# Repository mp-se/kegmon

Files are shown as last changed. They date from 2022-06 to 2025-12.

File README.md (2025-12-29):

 









# KegMon - Monitoring the volume in your kegs

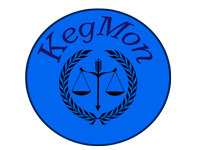
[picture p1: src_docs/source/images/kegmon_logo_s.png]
KegMon Logo


This is a project that I have done for my own Keezer, if you like it please feel free to suggest improvements. 

For docs see: https://mp-se.github.io/kegmon/index.html

# Hardware

* Supports ESP8266 D1 mini, ESP32s2 mini or ESP32s3 mini
* Loadcells and HX711/NAU7802 ADC converters
* DS18B20, DHT22, BME280 or BrewPI(IP) temperature sensors
* OLED 0.96" or LCD 20x4/20x2 displays

# Features

* Can measure weight from 1 or 2 scales
* Stable scale presentation (data is filtered and processed)
* Support temperature/humidity sensor in one scale base
* Integration with Brewfather to retrive data on brew
* Integration with Brewspy to retrive data on brew and also update the remaning volume and pours
* Integration with Home Assistant
* Weights and Volumes in Metric, Imperial (both US and UK)
* Pour detection for pours over 100 ml
* Estimation on how many glasses remain in the kegs
* Firmware update via UI
* One build for all hardware options
* Modern HTML5 UI
* Easy scale calibration
* 3D models and PCB

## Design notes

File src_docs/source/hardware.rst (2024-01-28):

.. _hardware:

Hardware 
--------

Introduction
============

The software will adopt to what external sensors are connected and will work with 
one, two scales, one or two displays and with/without a temperature sensor. 

The graph here shows two of my scales in my keezer where the second one (lower graph) is quite 
stable over time. The first one is not. The difference is over 2 kg and it goes back to the previous 
weight after a few hours. 

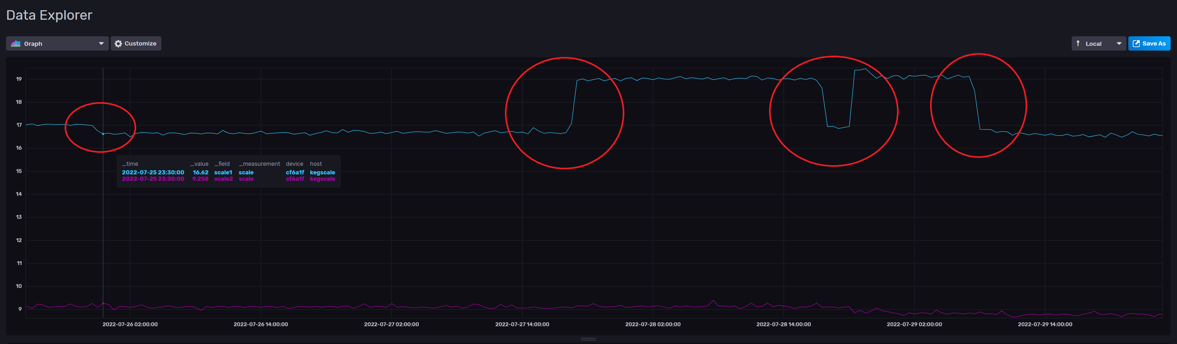
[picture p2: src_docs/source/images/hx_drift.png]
Scale drift


HX711
=====

I found 3 main types of HX711 boards and the green board has a different pin configuration compared to the 
other boards. 

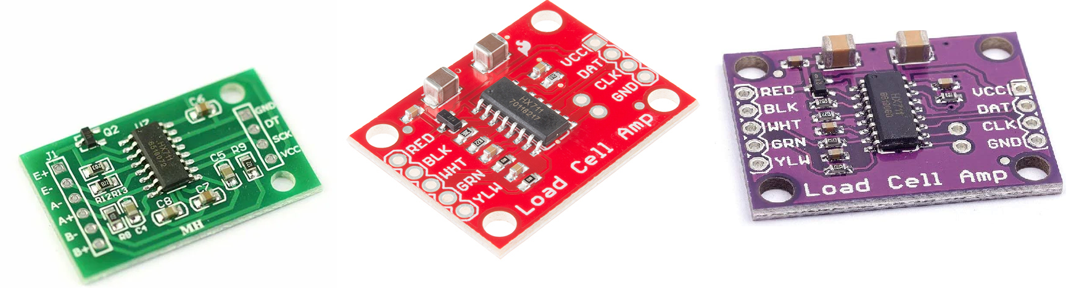
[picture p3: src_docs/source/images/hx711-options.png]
HX711 boards


* Green: Most common board when searching for HX711
* Red: Sparkfun board
* Purple: A variation of the Sparkfun board

The SparkFun board is the most expensive one but has one major advantage. You can power it on +5V and 
configure it to use 3.3V digital signal levels (using VCC and VDD pins). 

The main option used in this project is the purple HX711 board. The green board dont have the same pin configiuration 
so this will not work with the PCB design.

NAU7802
=======

This is the alternative ADC which is quite new and I have not had the time yet to validate the long term stability. 

These boards use the I2C bus for communication so these needs a differnt hardware wiring. Since you cannot change the 
adress on these boards you need to an ESP32 if two scales will be connected since the ESP8266 only supports one I2C bus.

.. note::
  If you are using this you need to change this in the configuration menu and restart the device for it to work 
  properly. 

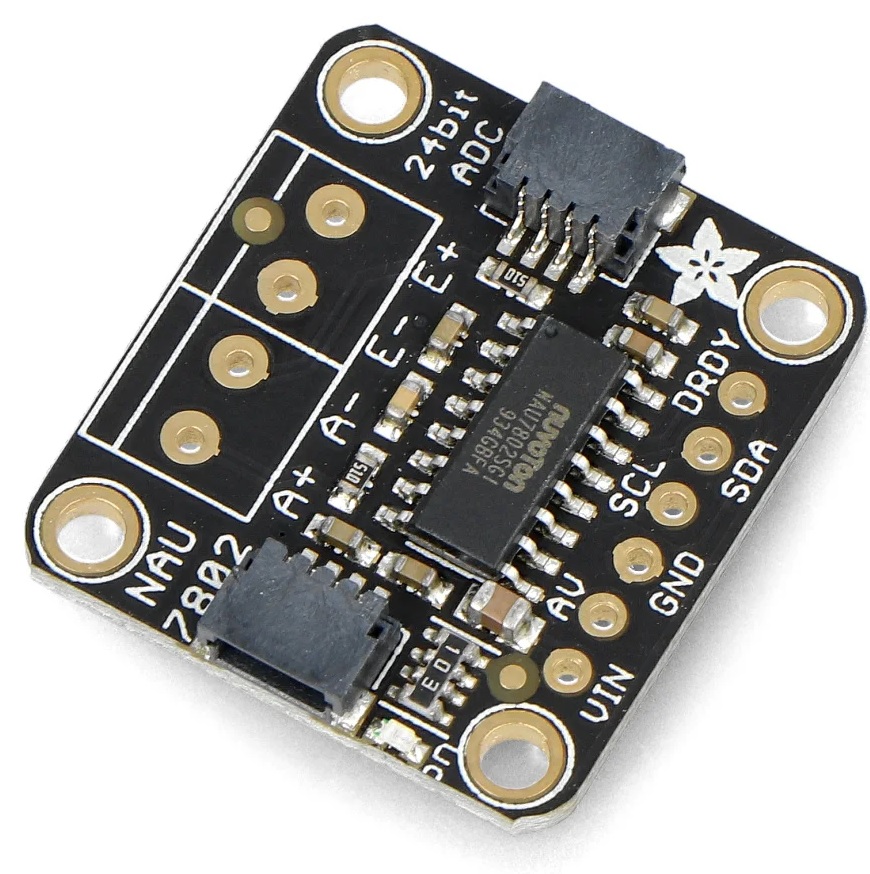
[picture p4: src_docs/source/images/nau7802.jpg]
NAU7802


Schema for HX711
================

.. note::
  The temperature sensor is installed in the scale base and you can use either a DS18B20, DHT22 or BME280. I would recommend 
  the DS18B20 since that is more stable and cheaper than the DHT22. The BME280 uses an I2C bus so this will require a different 
  wiring than the other options.

This is the schema used for the default hardware options. 

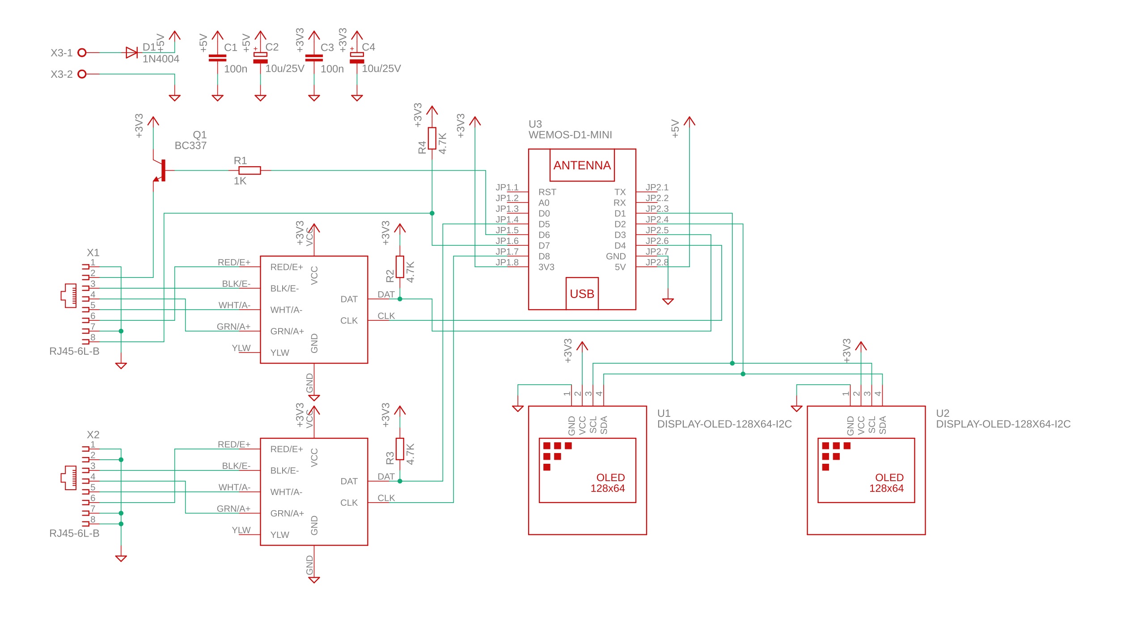
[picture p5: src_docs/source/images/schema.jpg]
Default hardware options


Schema for NAU7802
==================

This is the schema used for the NAU7802 boards. Scale 1 uses the same pins as the OLED displays. Scale 2 uses the same pins as 
for the HX711. So D3/D4 is unused in this variant. 

.. note::
  I'm considering to update the hardware design to fit a larger OLED display 1.3" and multiple NAU7802 on the ESP8266 platform but 
  this will require an i2c extender to avoid adress overlap. 

.. note::
  Note that the ESP8266 only supports one I2C bus so with that processor only one scale can be used. Recommend to use ESP32S2/S3 which 
  can support both NAU7802 scales.

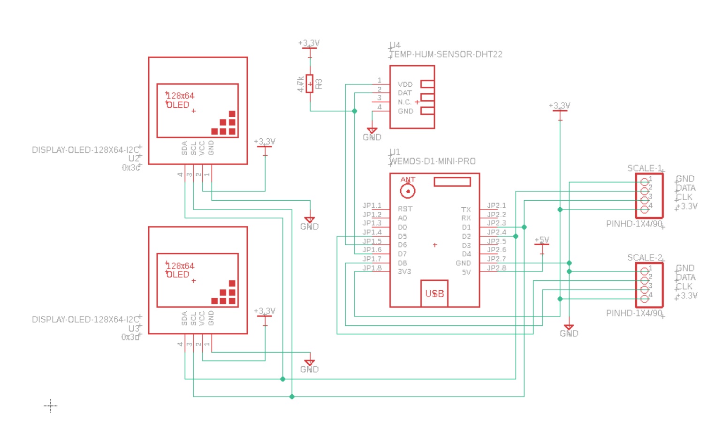
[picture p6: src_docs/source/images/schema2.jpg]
Schema NAU7802


Case
====
In this version the HX711 boards are moved to the case with the displays. The hope is that 
this would stabilize the sensor readings and also make it easier to replace a faulty scale. 

Part list:

* U1 - Wemos ESP8266 D1 mini - option 1
* U1 - Wemos ESP32 S2 mini - option 2
* U2/U3 - 0.96" 128x64 I2C OLED display (i2c adresses, 0x3c + 0x3d) - option 1
* U2/U3 - LED 20x4 I2C display (i2c adresses, 0x27 + 0x26) - option 2
* R1 - 4.7k (only used with HX711)
* R2 - 4.7k (only used with HX711)
* R3 - 3.3k
* 2 x HX711 boards
* 5V power supply
* RJ45 connectors if you want to remove the scales
* PCB (work in progress)
* 3D printed case for displays and esp8266 (work in progress)

R1 and R2 are just used to pull the CLK to +3.3V or the code will not detect 
that scales are missing (floating input). You can use most values between 
2k and 5k for that.  

It's possible to use the NAU7802 boards to replace the HX711 ADC. Two scales is only supported on the ESP32 platform since it requires 
two i2c bus instances. The wiring is different if you choose this option. 

* 2 x NAU7802 boards (require the ESP32S2/S3 for two scales)

Images below shows examples of a HX711 board and RJ45 breakout board. 

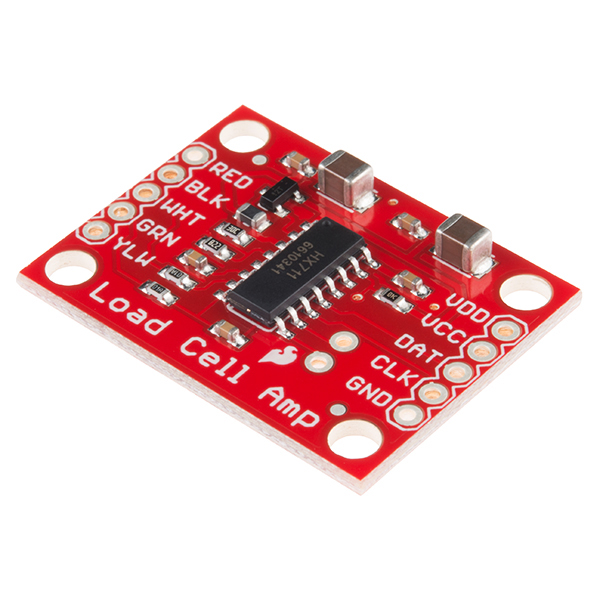
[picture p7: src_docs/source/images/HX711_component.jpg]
HX711 board


If you are using the Sparkfun board I suggest that you power the HX711 board with +5V (VCC) and +3.3V (VDD) 
so the digital interface is compatible with the ESP. 

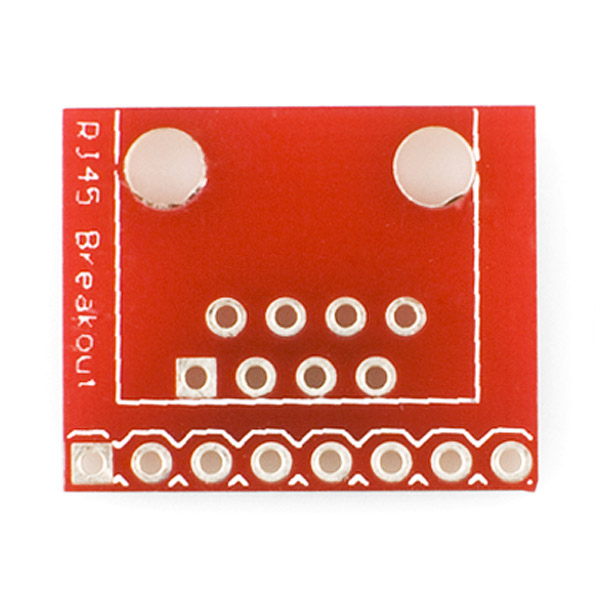
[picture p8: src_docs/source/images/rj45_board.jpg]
RJ45 board


.. list-table:: ESP pins
   :widths: 60 20 20
   :header-rows: 1

   * - Function
     - ESP8266
     - ESP32S2
   * - DISPLAY SDA 1 and 2
     - D2
     - 33
   * - DISPLAY SCL 1 and 2
     - D1
     - 35
   * - NAU7802 SDA 1
     - D2
     - 33
   * - NAU7802 SCL 1
     - D1
     - 35
   * - HX711 DATA 1
     - D3
     - 18
   * - HX711 CLK 1
     - D4
     - 16
   * - HX711 DATA 2
     - D5
     - 7
   * - HX711 CLK 2,
     - D8
     - 12
   * - NAU7802 SDA 2
     - D5
     - 7
   * - NAU7802 SCL 2
     - D8
     - 12
   * - Data to DHT22 or DS18B2
     - D7
     - 11
   * - BME280 SDA
     - D2
     - 33
   * - BME280 SCL
     - D1
     - 35
   * - Power to DHT22, DS18B2, BME280
     - D6
     - 9

Building the display case
*************************
  
First step is get a pcb and to print the two case parts. This first version is a one sided pcb. 
In the future there will be a multisided one. 

The models for the case is found under the /3d folder and the pcb files under /schema

Solder the components / or the mounting pins to the PCB as shown in the image below.

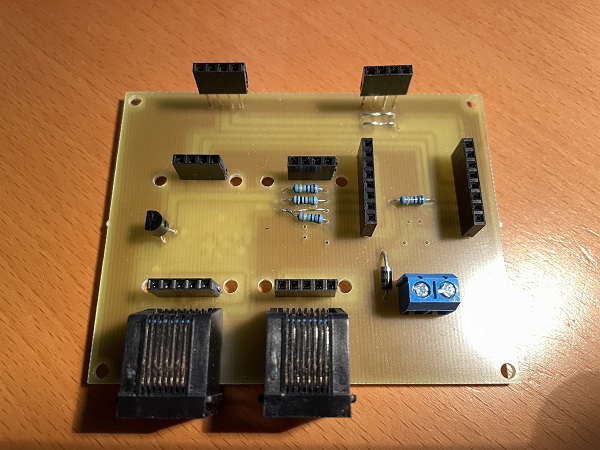
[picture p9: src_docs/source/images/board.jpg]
Soldering


Here is a view with all the components mounted.

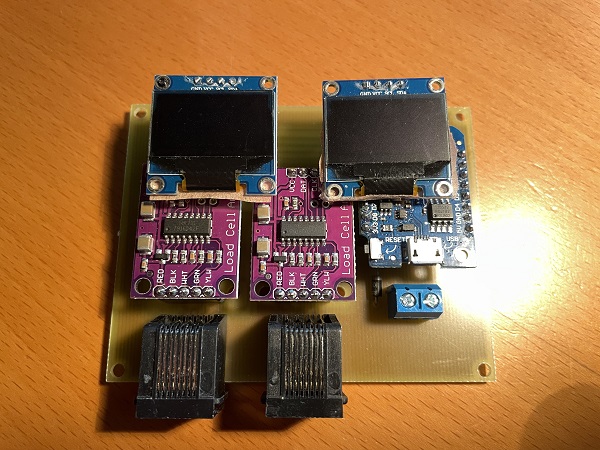
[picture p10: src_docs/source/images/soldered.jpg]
Soldered all components


Fit into the case.

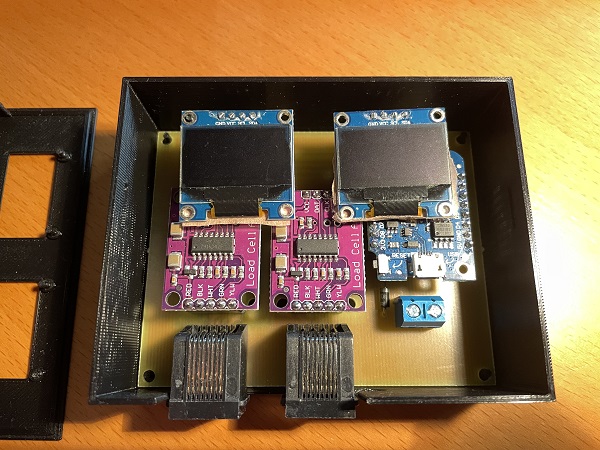
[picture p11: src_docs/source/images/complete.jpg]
Mounted in case


I use hot glue to fix the displays in place. 

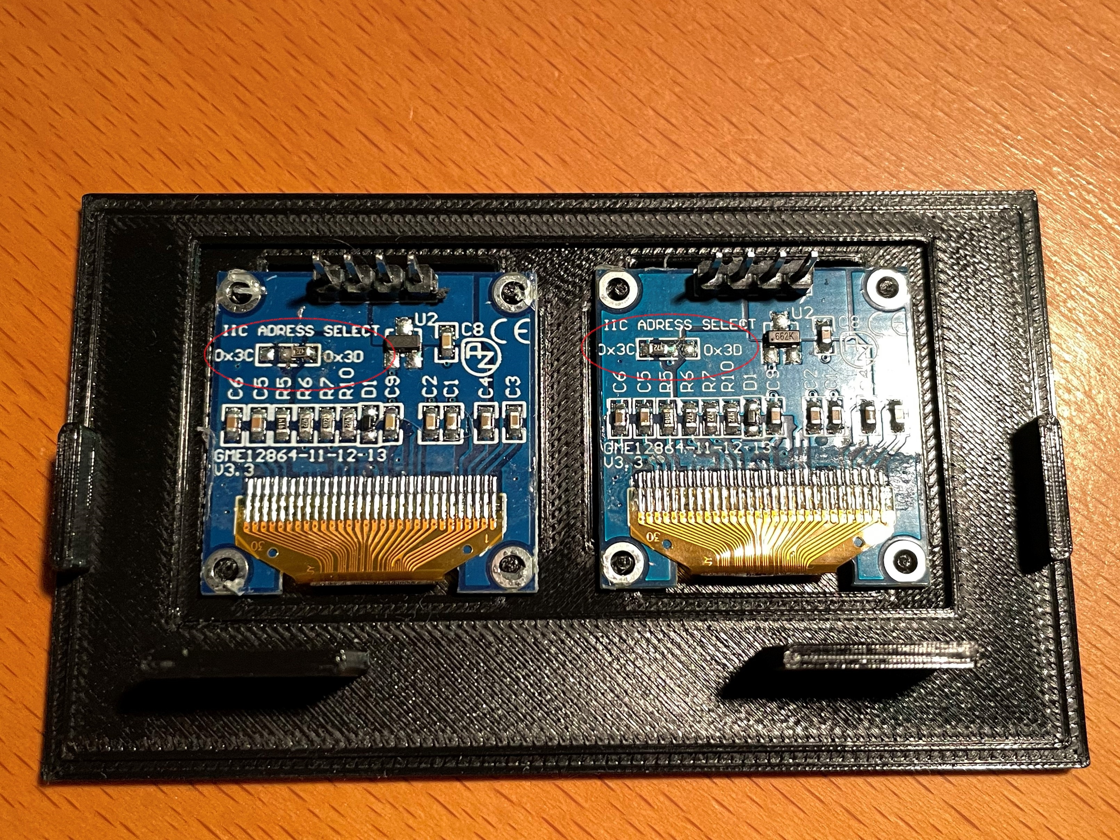
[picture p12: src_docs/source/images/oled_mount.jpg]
Mounting displays


Here is a view of the completed build.

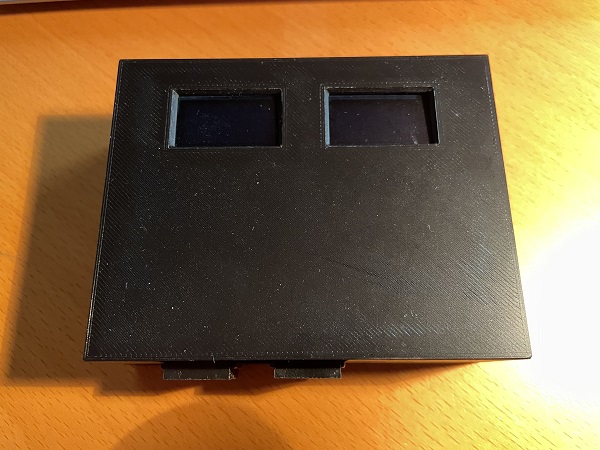
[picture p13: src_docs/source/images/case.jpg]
Complete


Scale Base
==========

In this version the base is just a frame for the load cells and the temperature sensor. 
Each base will have the same build process but only the temperature sensor of one will be used.

* 3D printed base
* 3D printed cover
* 4 load cells 
* CAT6 network cable
* U4 - DHT22 temp and humidity sensor (optional, alternative 1)
* U4 - DS18B20 temp sensor (optional, alternative 2)
* U4 - BME280 temp sensor (optional, alternative 3)
* Load Combinator PCB (optional)

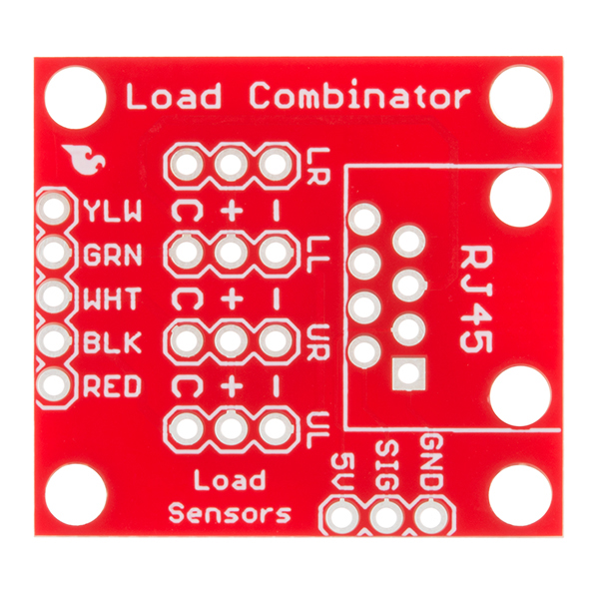
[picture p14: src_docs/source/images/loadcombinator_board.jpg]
Load Combinator board


Building the base
*****************

Print the 2 base models and 2 covers. Files can be found in the sub-model directory. 
These models are designed to be printed on my Prusa MK3s+ and support a Cornelius  
kegs of 9, 18 or 19 l.

`An alternative design can be found here <https://github.com/darkside90a/kegmon-base>`_

You can of course print or build a different mount for the load cells. Just check the 
internet and you will find several options. Mount the load cells in the base and wire 
the HX711 board to the load cells as shown in the next picture. Excellent guide on how to
`hook up loadcells and use the combinator board <https://learn.sparkfun.com/tutorials/load-cell-amplifier-hx711-breakout-hookup-guide/all>`_

First I start with soldering some wires to the DHT22 sensor so I can mount that in
the base together with the load cells. You can also use a DS18B20 sensor which is wired 
in the same way (Power, GND, Data).

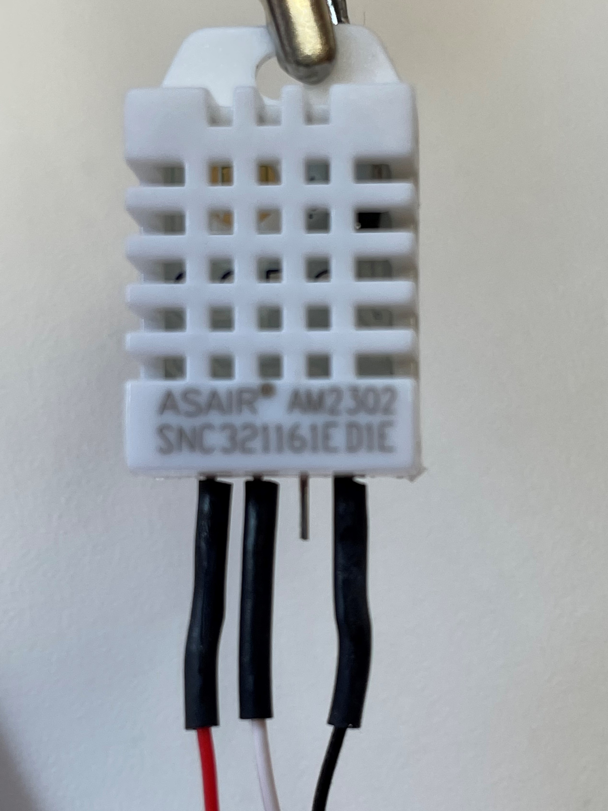
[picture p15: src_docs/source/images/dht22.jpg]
dht22


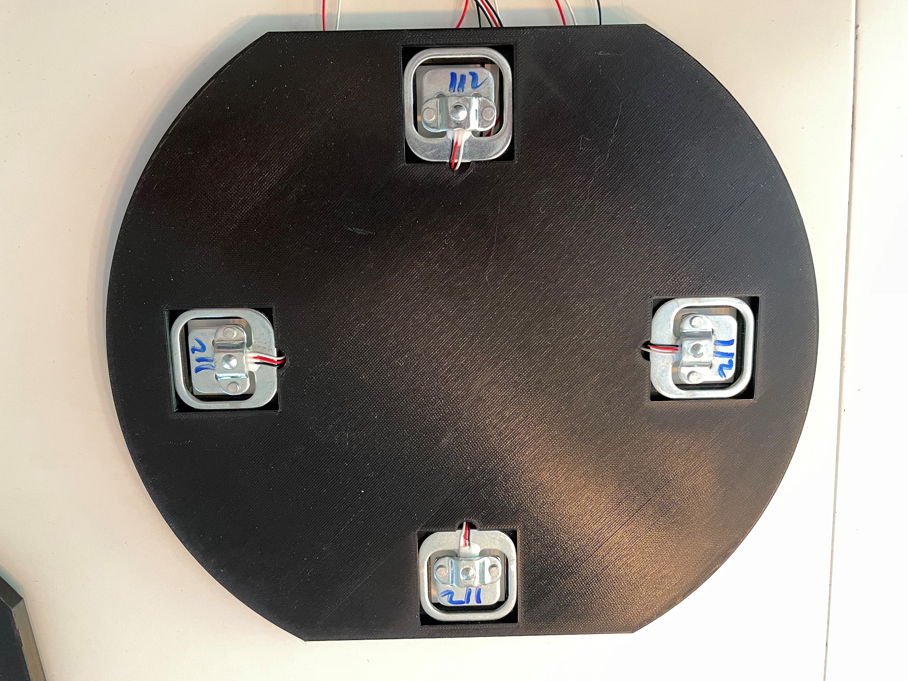
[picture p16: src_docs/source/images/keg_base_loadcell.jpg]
Load cells mounting


When you shorten the cables, make sure all of them are of the same length. Since the HX711 AD Converter will go in the display case the 
network cable will extend these cables anyway. 

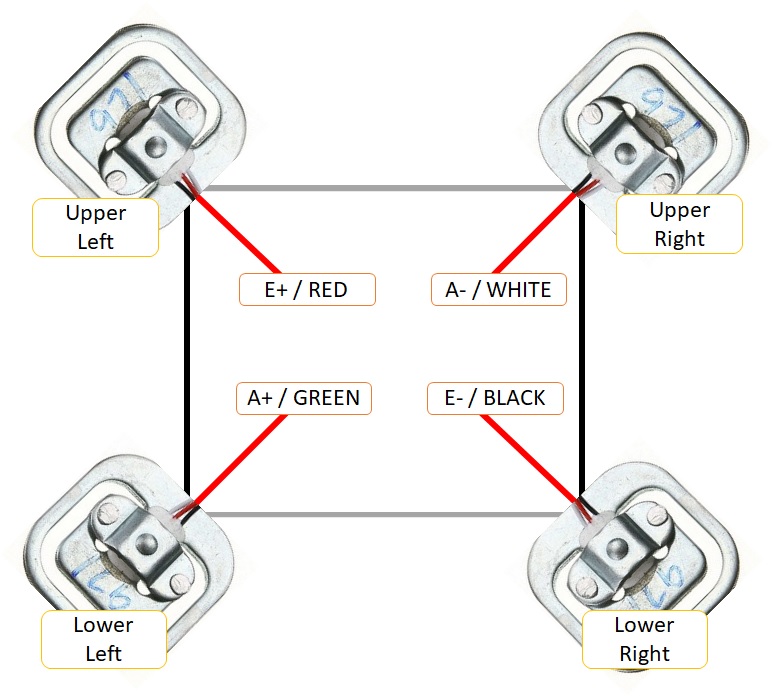
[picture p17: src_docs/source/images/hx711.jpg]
HX711


I used a flat network cable (CAT6) for the connection between the bases and the HX711/ESP8266 and this is 
what the result looked like. The cover will be glued on top of this at a later stage (preferably 
when it works correcly). You can also use a shielded cable that would be more resistent too external
interferece.

Typically the colors of the load cells are black (-), white (+) and red (out). If you use the combinator board then C is for the read (out signal). But 
to be sure measure the resistance and it should be 1.5k over the +/- cables (or the highest resistace). 

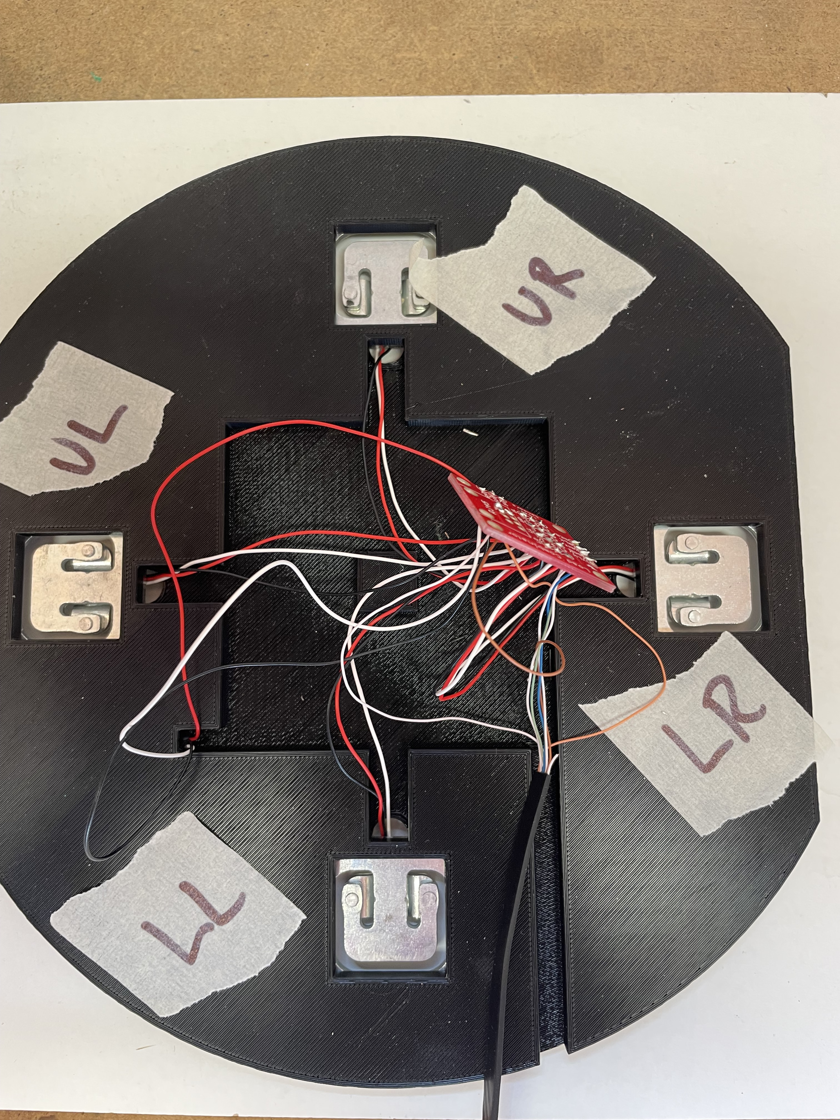
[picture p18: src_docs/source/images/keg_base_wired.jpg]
Wired base


Now the base is built and the next step is to test the stability over time. I hook up the base and calibrate it to so I'm happy with the base load. Then I 
let the weight rest on the scale for a couple of days to see how much deviation there is. In the software there is a feature for measuring the 
stability over time (Config->Stability). Once you have calibrated and placed the weight on the scale, navigate to this menu item and clear the values. These will only 
be reset at startup or when pressing the button.

CAT6 Wire Usage
***************

I used the following wires in the network cable to connect to each base. I used the combinator board to hook 
up all the cables from the load cells. You dont need that but I found it easier to keep track of what goes where. 
The base is quite thin so I cannot fit an RJ45 connector on the board so i'm connecting the cable wires directly to the 
combinator board.  

.. list-table:: CAT Wiring
   :header-rows: 1

   * - Wire (T568B)
     - HX711
     - NAU7802
   * - Orange-White (PIN 1)
     - GND to DHT22, DS18B20, BME280 (GND)
     - GND to DHT22, DS18B20, BME280 (GND)
   * - Orange (PIN 2)
     - Power to DHT22, DS18B20, BME280 (+3.3V)
     - Power to DHT22, DS18B20, BME280 (+3.3V)
   * - Green-White (PIN 3)
     - E- (or BLK on HX711)
     - E- (or BLACK on NAU7802)
   * - Blue (PIN 4)
     - A+ (or GRN on HX711)
     - A+ (or GREEN on NAU7802)
   * - Blue-White (PIN 5)
     - A- (or WHT on HX711)
     - A- (or WHITE on NAU7802)
   * - Green (PIN 6)
     - E+ (or RED on HX711)
     - E+ (or RED on NAU7802)
   * - Brown-White (PIN 7)
     - GND or BME280 (SCL)
     - GND or BME280 (SCL)
   * - Brown (PIN 8)
     - Signal from DHT22, DS18B20 or BME280 (SDA)
     - Signal from DHT22, DS18B20 or BME280 (SDA)

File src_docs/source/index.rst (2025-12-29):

.. KegMon documentation master file, created by
   sphinx-quickstart on Tue Jun  7 09:29:30 2022.
   You can adapt this file completely to your liking, but it should at least
   contain the root `toctree` directive.

Welcome to KegMon - Keg Level Monitor
-------------------------------------

.. note::
  Reflects version *v1.2.0*, Last updated 2025-12-29

Introduction
============

The software is tailored towards my personal needs and external services that I use, but suggestions are always 
welcome. 

The software has two interfaces, displays and web-browser. Integrations with external services is available, 
currently BrewFather, BrewSpy and Home Assistant. If you have requests for other services raise a request on github. 

The cheap load cells are quite unpredicteble so it's hard to get a fully accurate and stable system. In order to 
compensate for this I have built in the possibility to add filters and clean up the values, these filters include:

* raw average (makes an average over the last 10 readings)
* kalman (smooths out the peaks readings, but slows down level detection)
* temperature adjustment (this is not yet active, but its possible to add a formula and adjust the weight, for instance compensate for temperature)

Here are two views on the data change over time, the temperature in my keezer is between 4 and 5 degress Celcius. My two 
scales behave diffrently even though the load cells are from the same batch. I guess that the peak in the first 
graph is due to interference from the compressor when it starts to cool. The orange line shows the stable level that 
is used. Level change is triggered by a change up or down of more than the threasholds. In the image below the peak 
is approx 16-20 cl above the stable level, so its not a big difference.  

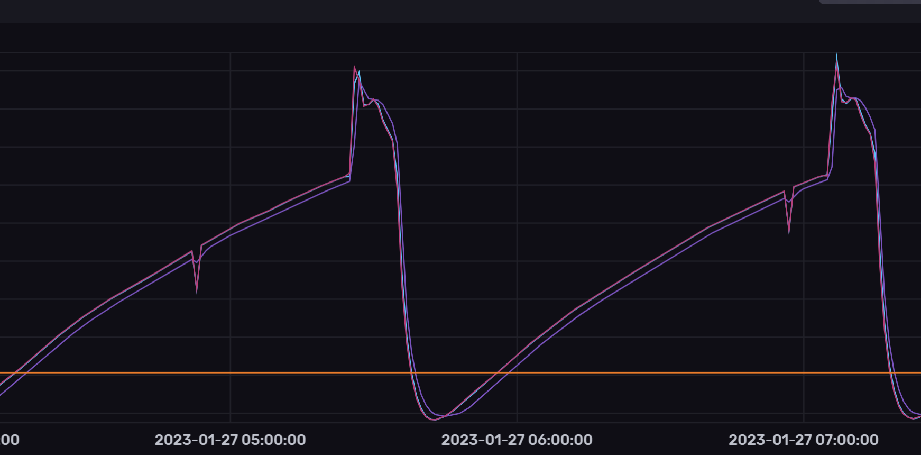
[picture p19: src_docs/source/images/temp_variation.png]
Scale variation


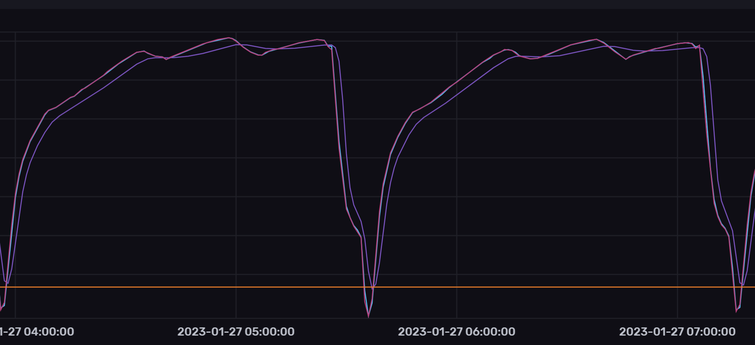
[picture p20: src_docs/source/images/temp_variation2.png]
temp_variation


Since the level will vary slightly based on the temperature (on my scale +0.04 to -0.01 kg), I have added a level detection algorithm
that uses the average level over time and dont adjust unless the delta is larger than the defined threasholds (can be set in configuration).

In order to trigger a level change then both the raw values and the kalman value needs to be aligned and the minium level change 
must exceed 10 cl. This means that a pour needs to be more than this level. It can take up to 60 seconds for a new level to 
be detected and a pour registered. This means that if you pour a number of glasses quickly, this will be detected as 
one large pour. 

The design is created for 2 kegs but it will work if you only use one (make sure to use the pins for scale 1 in that case). 

The displays will show the name of the beer, abv and alternate between weight and pours. The first screen will display 
values for keg 1 and the second for keg 2.

The values presented on the displays is the raw values so that you can see directly if the level changes. Stable values can be screen
at the web UI or via the external integrations.

The software will automatically detect how many sensor boards are connected and if there is a temperature sensor. 

The project contains the following parts:

* Software that manage the scale and present the readings
* Hardware design based on standard HX711 AD converter with load cells and temperature sensor
* 3D models for the base
* 3D models for display case

Help wanted
===========

I have not had the possibility to test / validate all the options so any feedback and updates to the documentation is appreciated.

Topics that need verification:

* Using BME280 in a scale base to measure temperature
* Using NAU7802 ADC to measure weight

Hardware options
================

Display 
*******

For display there are two options that can be used:

* OLED 0.96" display based on SH1106
* LED display based on PCF8574, both 20x4 and 20x2 displays can be used. 

The *OLED 0.96" display* is the option that is the primary option used in the design. 

There are larger OLED displays that could be used, but most of these dont have the option to 
change I2C adress so this would require a different hardware design. 

ADC
***

For ADC there are a few options available: 

* HX711 based boards (3 main options, green, purple and red boards)
* NAU7802 requires a differnt hardware wiring. NAU782 uses I2C communication and for two scales an ESP32S2/S3 is required.

The *HX711 purple board* is the primary option used in the design. The green board has a different pin configuration. 

Temperature sensor
******************

For temperature sensor you can use:

* DS18B20, one wire sensor
* DHT22, one wire sensor
* BME280, i2c sensor. This option require a different wiring

The *DS18B20 temperature sensor* is the primary option.

Credits to
==========
Thanks to the following projects.

* https://github.com/mp-se/gravitymon
* https://github.com/mp-se/espframework
* https://github.com/graphitemaster/incbin
* https://github.com/thijse/Arduino-Log
* https://github.com/bblanchon/ArduinoJson
* https://getbootstrap.com
* https://jquery.com
* https://chartjs.org
* https://github.com/bogde/HX711
* https://github.com/ThingPulse/esp8266-oled-ssd1306
* https://modelviewer.dev/
* https://github.com/RobTillaart/Statistic
* https://github.com/denyssene/SimpleKalmanFilter
*	https://github.com/mp-se/ESPAsyncWebServer
*	https://github.com/mp-se/ESPAsyncTCP
* https://github.com/adafruit/Adafruit_BME280_Library
* https://github.com/enjoyneering/LiquidCrystal_I2C
* https://github.com/sparkfun/SparkFun_Qwiic_Scale_NAU7802_Arduino_Library

.. toctree::
   :maxdepth: 2
   :caption: Contents:

   functionality
   releases
   intro
   hardware
   3dmodels
   installation
   configuration
   license
   development
   q_and_a

Indices and tables
==================

* :ref:`genindex`
* :ref:`modindex`
* :ref:`search`

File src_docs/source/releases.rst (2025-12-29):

.. _releases:

Releases 
########

v1.2.0
======

* (Bug) Fixed the issue that page did not show when integrations was updated last
* Upgraded depdendencies to latest versions
* Force device to scan for the strongest AP when connectiing to wifi.

v1.1.0
======

* Added new integration to BrewLogger (TapList/Pour Logging)
* Added new integration to Chamber Controller (Temp Sensor)

v1.0.0
======

* Added new integration to Barhelper
* Updated documentation
* Added push feedback to UI to check status of integrations
* Change wire speed to 400 Mhz (Speed up display rendering)
* Added influx integration for scale data (debugging)
* Added favicon
* Created new user interface in VueJS and VITE
* Changed all REST API's to use json documents

v0.9.0
======

* Added new board esp32s3 mini
* Added option to fetch temperature from brewpi-esp installation
* Removed mobile dashboard, replaced with KegMonApp (see: https://github.com/mp-se/kegmonapp)
* Added support for ESP32s3 mini
* Fixed memory leak in temp sensor code

v0.8.0
======

* Added possiblity to run on wokwi simulator (work in progress, scales, file system not yet working)
* Added option for setting pins for external devices (display, scales and sensor)
* Added support for BME280 sensor + pressure information
* Refactor documentation to show the hardware options better
* Updating dependecies
* DS18B20 temperature sensor is not the default
* Updated code to support newer versions of ArduinoJSON

v0.7.1
======

* Fixed some issues with logging changes in levels so that the logfile is not filled with data connected to startup events
* Fixed stability issue that could cause crashes
* Updated display layout (One) to show details on display 2 if attached

v0.7.0
======

* Added support for LED 20x4 displays
* Added a few new layouts including support for one single display
* Refactored the display logic to make it easier to change settings and share formatting among multiple rendering options. 

v0.6.0
======

.. note::
    Updating from the 0.5 async version requires a manual reset after upload is finished to apply the new software.

.. warning::
    Issues with connecting to DHT22 sensor on ESP32S2/S3 variant over long cables. Uncertain what causes this. Recommendation is to use DS18B20 instead on ESP32S2/S3.

* BUG: Configuration lost when JSON document became to large, increased buffer to 3kb (from 2kb)

* Added support for NAU7802 AD converter from sparkfun. Uses I2C bus. Will require ESP32S2/S3 for two scales and different wiring. This is EXPERIMENTAL!
* Added error message to restore configuration feature in case the ID did not match.
* Added pull-up resistor to temperature sensor data line (applies to both DS18B20 and DHT22)
* Added web based serial console accessed via http://device/serial or ws://device/serialws (only works with async webserver)
* Added mobile dashboard accessed via http://device/dashboard
* Added updated schema and pcb for the HX711 edition.
* Added 3d model for case that works with pcb
* Moved to async webserver as standard
* Added support for ESP32 s2 mini board
* Upgraded Arduino frameworks to latest stable + fixed problem in HX711 library due to Arduino update.
* Added backup & recovery function
* Created own code for multireset feature (for entering wifi setup)
* Refactored Wifi manager library since its not longer maintained by original author. Added logging output.

v0.5.0
======

* Experimental Async webserver support, this improves the speed of the web UI quite a lot but can be prone to crashes
* Level detection has been refactored and I added a Kalman filter to remove the worst interference.
* Added option to do temperature compensation of load cells in software (formula still to be concluded). Requires a temperature sensor close to the load cells.
* Added integration with Home Assistant (via MQTT)
* Added graphs in web interface that shows the stability (requires the web browser to be open, data storage and rendering is done in the browser)
* Added some advanced configuration options to define params used by the level detection algorithm.
* Refactored logoutput from WifiManager to be consistent with other logs.

v0.4.0
======

* Prepared support for 1.3" displays (other driver), but havent found any displays that can change I2C adress.
* Logging of pours and graph to show history
* Better stability & pour detection
* Integration with brewspy both for level updating and beer information (waiting for API to expose FG)
* Some redesign of the UI
* Hardware design has been updated to have separate CLK pints to the HX scales, I found that this would make readings more unstable.

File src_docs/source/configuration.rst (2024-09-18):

.. _software:

Software
--------

Index
*****

This is the web page accessed by accessing the device via a web-browser. This section will show the general device information.

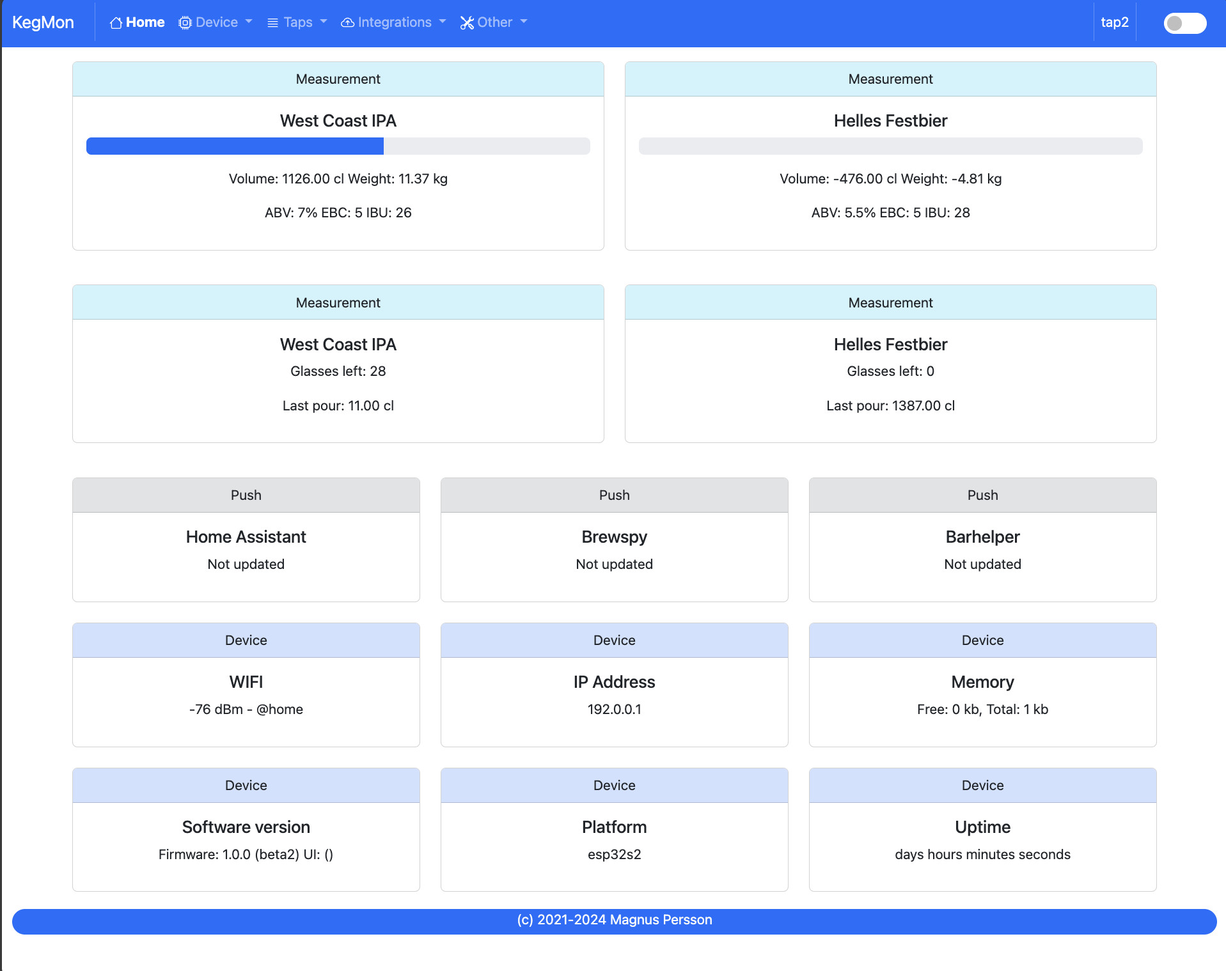
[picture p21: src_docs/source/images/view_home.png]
Index


Shows information about the device and temperatures, only data available will be shown.

Device - Settings
*****************

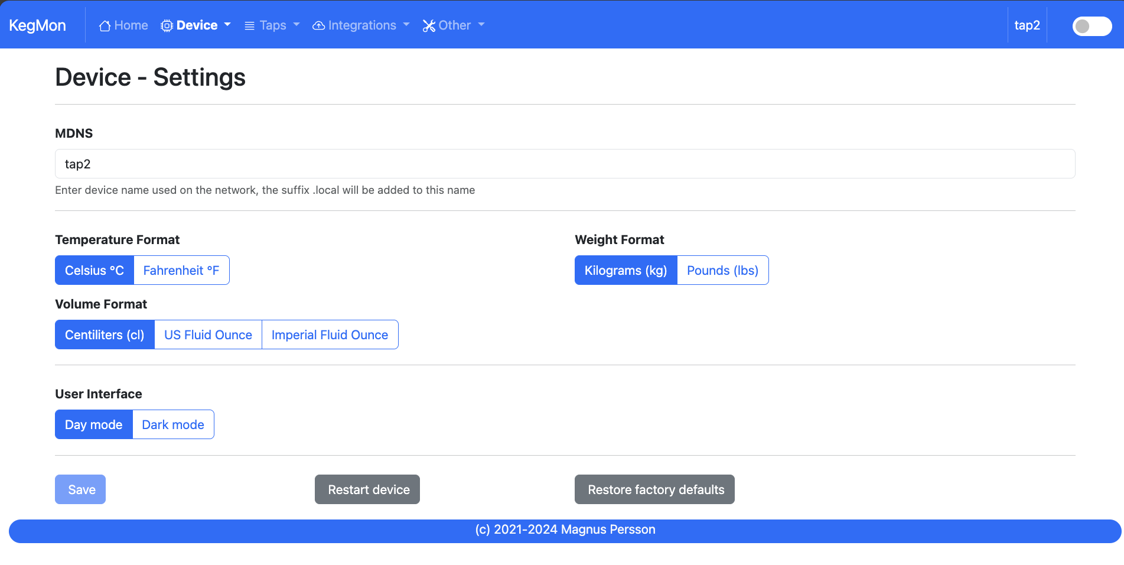
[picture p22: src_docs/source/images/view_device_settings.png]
Device Settings


* **Device name**: Set the name of the device on the network, your network needs to support mDNS.

* **Temperature format**: Select format for temperatures

* **Weight unit**: Select format for weights

* **Volume unit**: Select format for volumes

* **Dark Mode**: Switches the UI between light and dark mode. You can also use the toggle on the menubar for that.

Device - Hardware
*****************

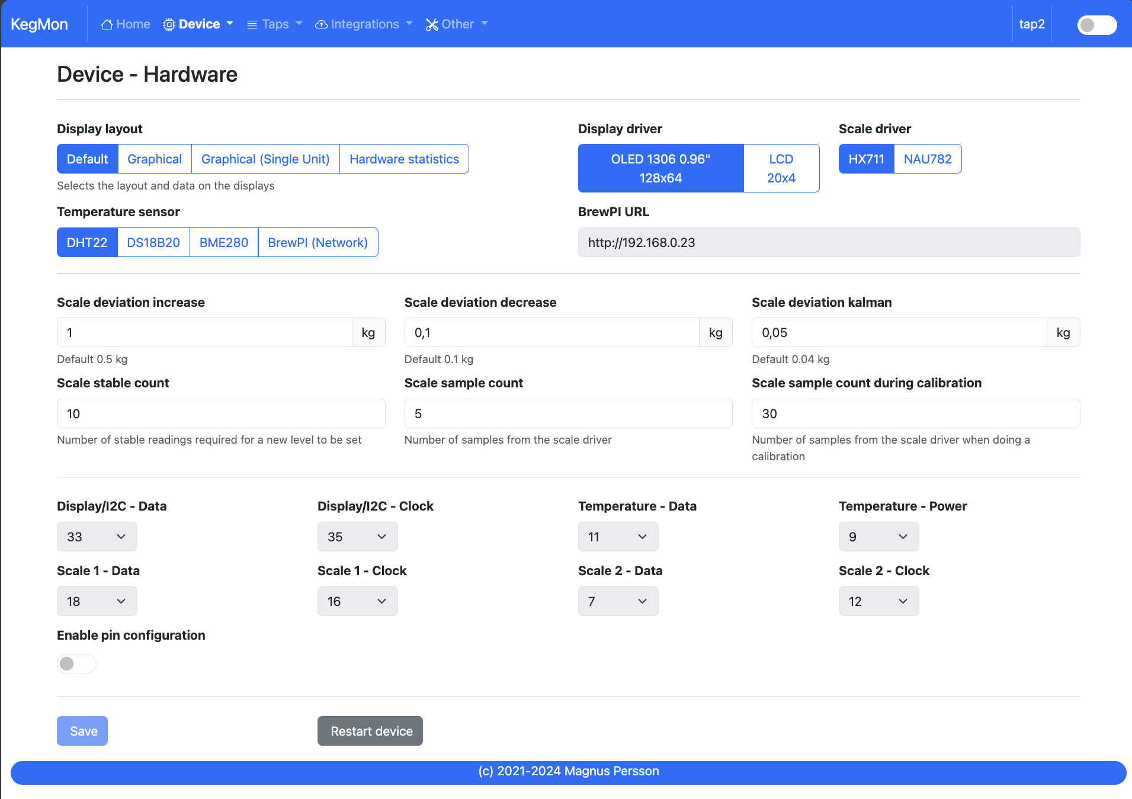
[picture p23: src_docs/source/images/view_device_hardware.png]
Device Hardware


* **Display layout**: Choose the layout/information on the displays.

* **Display driver**: Choose the what display driver is used, either LCD 20x4 or OLED 0.96". Default is OLED 0.96".

* **Temp sensor**: Choose the what temp sensor is used, either DHT22, BME280, DS18B20 or remote BrewPI-ESP installation. Default is DS18B20. *Wiring for BME280 is different*.

* **Scale sensor**: Choose the what ADC is used, HX711 or NAU7802. Default is HX711. *Wiring for NAU7802 is different*.

* **BrewPI ESP URL**: Base URL for the brewpi-esp to fetch temperature from. Require v15 or later. 

* **Pins**: If you dont follow the standard hardware wiring then you can customize the pins here.

Device - Calibration
*********************

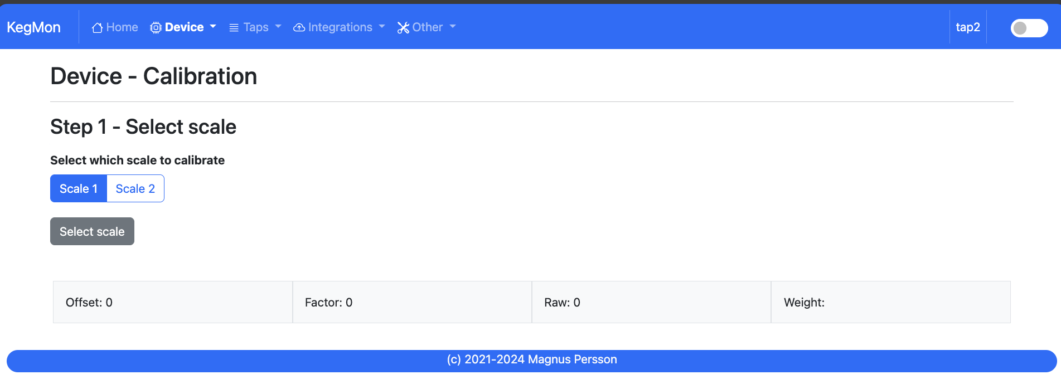
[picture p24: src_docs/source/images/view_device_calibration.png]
Device calibration


* **STEP 1 - Tare scale**

The first step is to tare the scale. First select the scale from the dropdown list that you 
want to operate on. Make sure the scale is empty.

* **STEP 2 - Calculate factor**

The second step is to calculate the factor used to calculate the weight. Place a thing with a 
known weight on the scale and enter the weight of that object. The software will then calculate
the factor for estimating the weight. 

* **STEP 3 - Validate**

The third step is to validate that everything works, place anohter thing with a know weight and 
check the measured value. If you are satisfied then you are done.

Device - Stability
******************

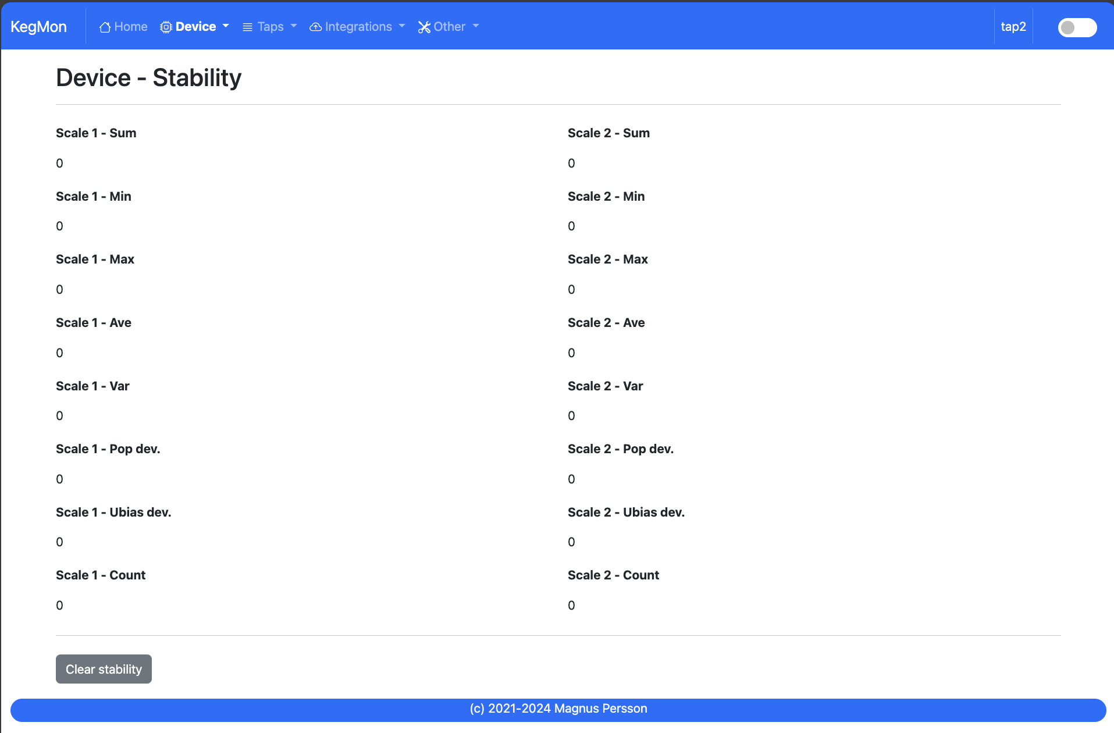
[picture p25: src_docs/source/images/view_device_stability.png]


Information page that can determine the stability of your hardware build.

I have found that some of my hardware builds was not really stable so I added this 
feature to check the scale build before doing the final assembly. 

If you keep the browser open you can also see the history of the values (raw, kalman & stable). This can help to show
how your scale varies over time. Data is only stored in the browser so any refresh or page change will delete the graphs.

Device - Wifi
*************

Device wifi

* **SSID #1:**

  Select the desired primary SSID to use. 

* **Password #1:**

  Enter the primary password. 

* **SSID #2:**

  Select the desired secondary SSID to use (optional). 

* **Password #2:**

  Enter the secondary password (optional). 

* **Portal timeout:**

  If the wifi portal is triggered (can be triggered by tapping the reset button 2-3 times within 3 seconds) then this is the amount of time allowed before it exists again.

* **Connect timeout:**

  This is the amount of time allowed for a wifi connect. 

Taps - Settings
***************

Tap settings

* **Empty keg weight**: Weight of the empty keg, used to determine how much beer is in the keg.

* **Glass volume**: Choose the volume of the beer glasses, used to determine how many pours are left. 

* **Beer name**, **Beer ABV**, **Beer EBC**, **Beer IBU**: Information about the beer, used to show on user interfaces.

* **Beer FG**: Used in formula for calculating the beer volume. FG has a slight impact on the weight / volume unit. If not defined 1 will be used for calculations.

Taps - Beers
************

Tap beers

Shows information about beers on tap. Use the buttons to import from brewspy or brewfather.

Taps - History
**************

Tap history

Shows information about the latest pours per tapbeers on tap.

Integration - Home Assistant
****************************

Home Assistant integration

Setting for MQTT server that is used by Home Assistant.

Integration - Brewfather
************************

Brewfather

API and User keys for access to brewfather

Integration - Brewspy
*********************

Brewspy integration

Brewspy tokens for keg 1 & keg 2. 

Click on the taplist and the tap you want to connect. Under webhook URL copy the 
last code and enter that into kegmon.

.. note::
  This will not work on ESP8266 due to lack of RAM for using SSL connections.

Integration - Barhelper
***********************

Barhelper integration

Barhelper API keys and name of monitors.

You can get the API key from the settings part of Barhelper and enter this into 
kegmon. Make a copy of it since you will not be able to retrieve it again. 

The name of the monitors does not need to be registered, they will be added 
after the first run. Just connect the tap/keg to the monitor and the level will 
be the same as in kegmon.

.. note::
  On ESP8266 the device will use a NON-SSL endpoint to send the data since there is 
  not enough memory.

Integration - Influx
********************

Influx integration

Sends scale and internal parameters to an influx db v2 for debugging and detailed analysis.

Serial console
**************

Serial console

Here you can view the serial output from the device for troubleshooting

Backup & Recovery
*****************

Backup configuration

Backup your configuration or restore it from a previous state

Firmware update
***************

Upload firmware

Here you can upload a new firmware version without the need to hook the device to a serial port 
on your computer.

Support
*******

Support information

View logs or check the hardware configuration

Tools
*****

Tools

Interact with the file system on the device

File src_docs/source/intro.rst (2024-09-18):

.. _getting_started:

Getting started
===============

Step 1 - Build the scale bases
------------------------------

First you need to build the hardware which consists of 1 or 2 scale bases and a case with the displays and esp. 

Step 2 - Build the case
-----------------------

Currently there is only a schema on how this needs to be constructed. 

**Creating a PCB & 3D case is Work In Progress....**

Step 3 - Flash the device
-------------------------

The first step is to flash the firmware, I recommend using Brewflasher as the easy option. Detailed 
instructions can be found here :ref:`installation`

Step 4 - Setup WIFI
-------------------

When the device starts up the first time it will first start an WIFI access point so that the WIFI Settings 
can be configured. The instructions for that can be found here :ref:`setup_wifi`

.. note::
  Since the user interface is built using modern frameworks the device requires access to the internet 
  for the UI to render and data to be populated. The sites that are needed are; https://cdn.jsdelivr.net/npm/bootstrap
  and https://code.jquery.com

Step 5 - Configuration
----------------------

Once the device can connect to WIFI it will go into `wifi setup mode` and start a web server for 
doing the initial configuration. In order to access the device you will need to find its name or ip address.

It will broadcast a name like kegmonXXXXXX.local over mDNS. Where the XXXXXX is the unique device id. You can 
find the name via an mDNS browser, check your router or connect the device to a serial monitor. On windows mDNS 
might not work so then use the IP address instead. Once connected you will meet a web interface that looks like this.

Index page

In order for the software to work properly there are a few steps that needs to be configured. When you open up the
index page a selftest will be run and common issues will be shown for your action.

Configuration - Device Settings - Device Name
+++++++++++++++++++++++++++++++++++++++++++++

Give your device a good name.

Configuration - Calibration
+++++++++++++++++++++++++++

Place the scales on a flat surface and follow the 3 steps to calibrate each scale. Use a known weight to calculate the factor. Use 
a quite heavy weight for best result.

Configuration - Beer
++++++++++++++++++++

Enter the information on what beer you have in the kegs.

Step 4 - Completed
------------------

You are now done and can enjoy the KegMon software. 

**If you have suggestions for more awesome features, head over to the github repository and make a request.**

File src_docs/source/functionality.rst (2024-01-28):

.. _functionality:

Functionality
==============

The main features
-----------------

* **Lots of hardware options**

  One firmware that support multiple hardware opions. You can select displays, temperature sensors and ADC. Can be configured in the web UI.

* **Modern web based interface**

  Modern HTML5 based web interface with easy access to configuration and current status.

* **3 step easy scale calibration**

  3 easy steps to calibrate your scale all from the web interface. Tare the scale, calculate factor based on known weight and finally verify.

* **3D printable bases for kegs**

  3D models for keg bases or uses any of the other load cell bases that can be found. 

* **Hardware design for up to 2 scales**

  Software support one or two scale with attached displays for showing statistics.

* **Stable level detection**

  Software based detection for finding a stable level of each keg.

* **Pour detection**

  Can detect when a beer is poured. Needs to be more than 10 cl and there needs to be a stable level of approx 40 seconds after the pour.

* **Estimating remaning glasses/pints**

  Based on weight and final gravity the remaning volume can be calculated. The weight of the empty keg can be entered so that this is removed from the masurement. 

* **Integration with Home Assistant**

  Data can be sent to home assistant to show current beers, last pour, remaning glasses etc.

* **Integration with BrewSpy**

  Can fetch data from BrewSpy on what brews are current and update the level when changed. 

* **Integration with BrewFather**

  Can fetch information on last brews for easy import of data.

* **Load cell temperature compensation**

  Formula can be added to do temperature compensation for each loadcell.

* **Easy software updates**

  Upload new software via the web UI.

* **Temperature & Humidity sensor**

  Place a temperature sensor close to the base, this can be used to do temperature adjustments of the load cells using a formula. Supports either a DS18B20, BME280 or a DHT22.

* **Backup and Restore of settings**

  All the configuration of the device can be exported and stored as a text file (json). This can be used to restore settings in case of 
  hardware problems. You can also create a template of your settings and use that on multiple devices. Just make sure to change the "id" fields 
  to match your device id (can be found on the index page). 
 
* **Celsius or Fahrenheit**

  You can switch between different temperature formats. KegMon will always use *C* for it's internal calculations and 
  convert to F when displayed.

* **Kg or Lbs**

  You can switch between different weight formats. KegMon will always use *kg* for it's internal calculations and 
  convert to Lbs when displayed.

* **cl, UK fl. oz or US fl. oz**

  You can switch between different volume formats. KegMon will always use *cl* for it's internal calculations and 
  convert to other formats when displayed.

* **Customize pins and the hardware design**

  You can customize the pin configuration if you want to change the hardware setup.

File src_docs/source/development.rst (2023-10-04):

.. _development:

Development
===========

Development of this project is done in VSCode with the PlatformIO extension using Arduino for ESP8266 and ESP32. 

For the documentation we use SPINX and github pages for publishing.

Compliance to coding standards PRE-COMMIT is used with their standard rules for formatting and good cpp code. Any PR needs 
to pass this validation in order to be considered for merging.

The pipeline is build based on github actions and all firmware builds and documentation publishing is done using the 
defined github actions.

For testing there is a UNIT TEST target defined which currently needs to be run on hardware. The plan is to move this to 
WOKWI and their github action to run these after a completed build. There is also a python script that can be used to validate the 
output of the available API's to ensure they deliver what is wanted. 

Future
------

The following additions is being worked on. 

* WOKWI simulator, so that the software can be run wihtout the need for hardware. 
* WOKWI CI, to run the unit test and API tests during builds.
* Update PR checks to include builds and unit testing. 

Links
-----
If you want to start contributing these are links to the tools I use.

* https://code.visualstudio.com/ (Code Editor)
* https://platformio.org/ (Arduino development)
* https://wokwi.com/ (Simulator for ESP32)
* https://marketplace.visualstudio.com/items?itemName=HookyQR.minify (Extension for making HTML files smaller)
* https://marketplace.visualstudio.com/items?itemName=platformio.platformio-ide (Platform IO extension)
* https://marketplace.visualstudio.com/items?itemName=Wokwi.wokwi-vscode (Wokwi simulator extension)
* https://pre-commit.com/ (Code validation, need to run this in Linux/WSL)
* https://cli.github.com/ (Source code management)
* https://gitforwindows.org/ (Git for Windows)

Other projects that are of interrest for development

* https://github.com/nektos/act (Run github actions locally)

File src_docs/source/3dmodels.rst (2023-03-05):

.. _3d:

3D Models
=========

These models fit a cornelius keg of 18, 19 or 9 liters. Will fit smaller kegs as well. 

`The models can be downloaded from here <https://www.printables.com/model/258303-scale-base-for-load-cells>`_

Base
****

This is a base for the scale.

.. raw:: html

   <style>
   model-viewer { 
      width: 600px; 
      height: 600px; 
   }
   </style>
   <div>
   <script type="module" src="https://unpkg.com/@google/model-viewer/dist/model-viewer.min.js"></script>
   <script nomodule src="https://unpkg.com/@google/model-viewer/dist/model-viewer-legacy.js"></script>
   <model-viewer height=400 width=400 id="mv-demo" shadow-intensity="1" src="./_static/3d/base.glb" alt="Base" auto-rotate camera-controls poster=""></model-viewer>
   </div>

Cover
*****

This is a model for the cover that is placed on top of the wires to protect them.

.. raw:: html

   <style>
   model-viewer { 
      width: 600px; 
      height: 600px; 
   }
   </style>
   <div>
   <script type="module" src="https://unpkg.com/@google/model-viewer/dist/model-viewer.min.js"></script>
   <script nomodule src="https://unpkg.com/@google/model-viewer/dist/model-viewer-legacy.js"></script>
   <model-viewer height=400 width=400 id="mv-demo" shadow-intensity="1" src="./_static/3d/cover.glb" alt="Base Cover" auto-rotate camera-controls poster=""></model-viewer>
   </div>

Case
****

To be defined.

Case Top
********

To be defined.

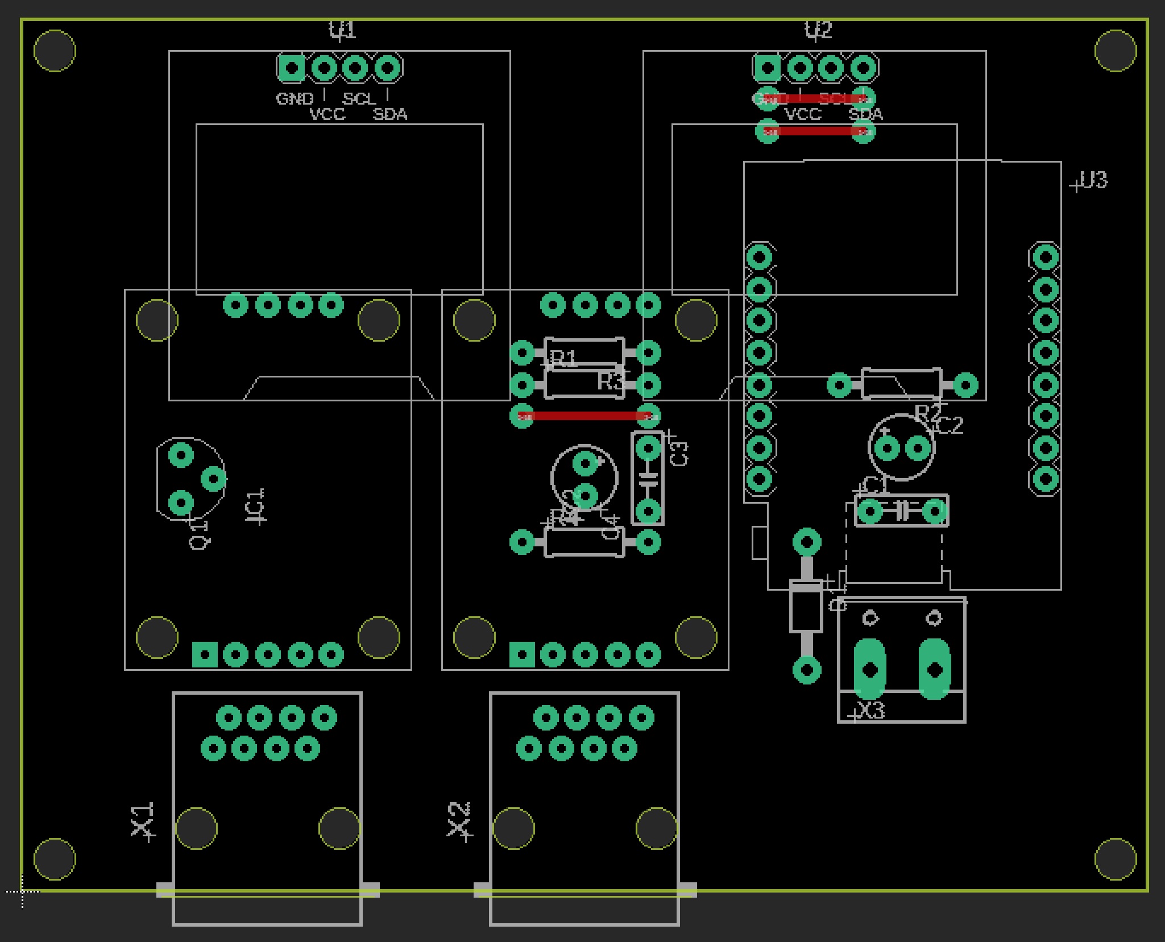
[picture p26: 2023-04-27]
src_docs/source/images/pcb.jpg

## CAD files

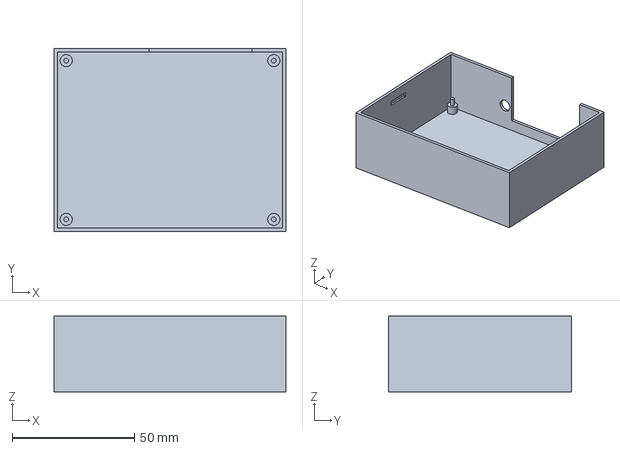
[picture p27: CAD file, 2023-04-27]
3d/case_base.3mf
95.0 x 75.0 x 31.0 mm

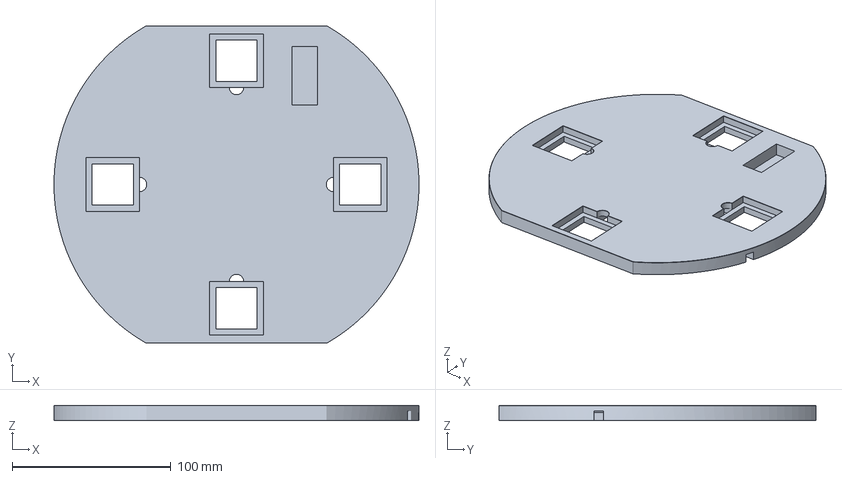
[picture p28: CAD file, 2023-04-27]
3d/scale_base.3mf
230.0 x 200.0 x 9.50 mm

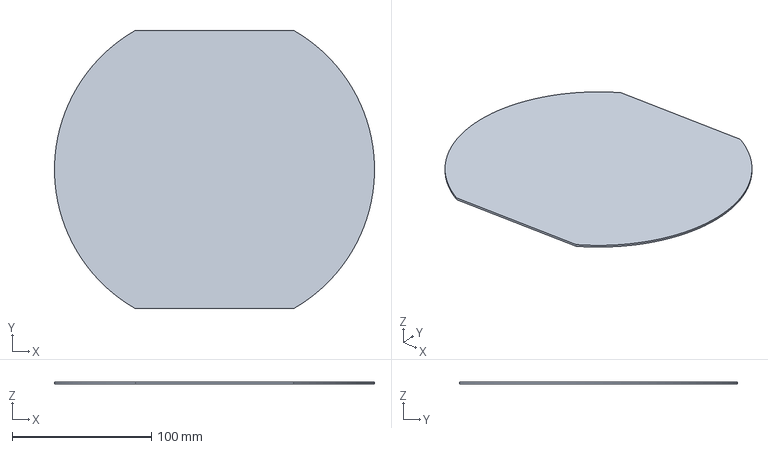
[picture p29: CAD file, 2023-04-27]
3d/scale_cover.3mf
229.9 x 200.0 x 1.50 mm

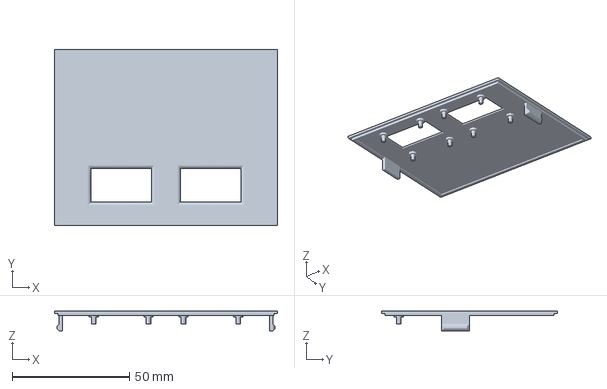
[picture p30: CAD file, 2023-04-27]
3d/case_lid.3mf
95.0 x 75.0 x 8.50 mm

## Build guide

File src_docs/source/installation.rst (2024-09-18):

.. _installation:

Software Installation 
---------------------

Checklist for configuring the device
====================================

Install the firmware using one of the following options:

- Brewflasher via USB serial
- Brewflasher WEB via USB serial

Brewflasher
===========

The preferred option for flashing KegMon is using BrewFlasher, its a tools that support many brewing related firmwares for ESP8266 and ESP32. This works 
on both Windows and Mac. You can download the latest version from here: `Brewflasher <https://www.brewflasher.com/>`_ there is also a web based version 
available here `Brewflasher WEB <https://web.brewflasher.com/>`_.

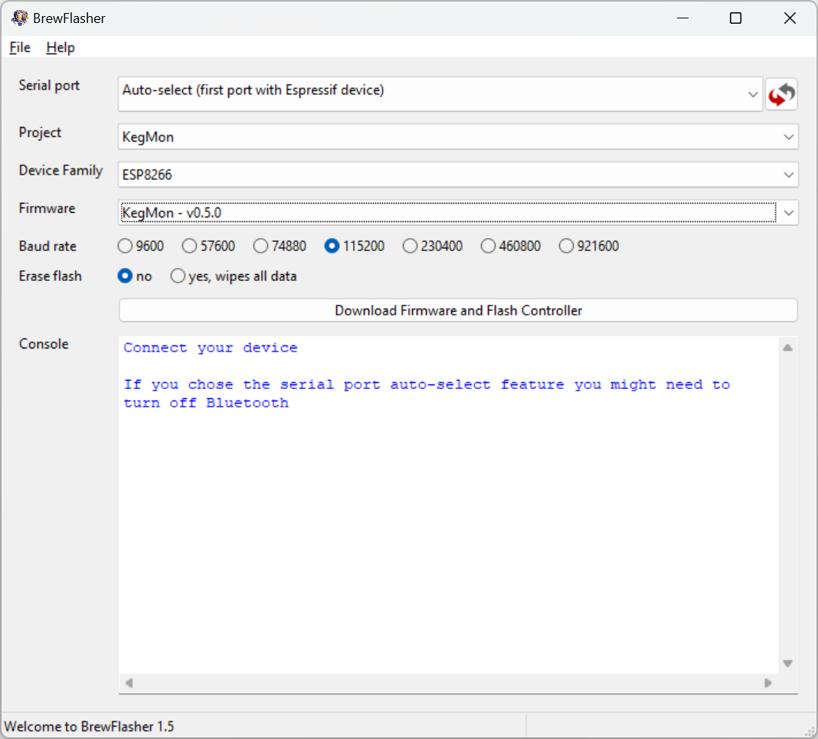
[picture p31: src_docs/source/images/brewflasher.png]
Serial output


Binaries
********

In the /bin directory you will find 2 different firmware builds;

* **firmware.bin**

  This is the standard release build for esp8266

* **firmware32s2.bin**

  This is the release build for an esp32s2 variant. 

* **firmware32s3.bin**

  This is the release build for an esp32s3 variant. 

Updating firmware 
=================

You can use the above options for updating the firmware as well. But if you want to do updates without connecting the USB cable these 
are your options.

Manual update
*************

When the device in is configuration mode you can manually update with a new firmware. Just navigate to configuration -> fimware select the firmware.bin or firmware32s2.bin file 
that corresponds to the version you want to flash. 

.. _serial_monitoring:

Serial Monitoring
=================

To check output from the device (logs) there are several tools out there. I found this simple tool in the Windows Store called ``Serial Port Monitoring``. 
Just select a baud rate of 115200, 8N1.

.. _setup_wifi:

Configuring WIFI
================

When the device is flashed it will need to have WIFI configuration in order to work. If you have used other software on 
the device its possible that wifi settings already exist.

If you have difficulties to connect to the create Access Point then try to do a reset and try again. Every time the AP 
is create it chooses a random channel. 

If this is not configured in the device it will create an wireless access point called `KegMon`. The default password is `password`.

Connect to this AP and enter the SSID and password you want to use. If the web page don't open automatically you can enter the following address 
in the browser: **http://192.168.4.1**

Before pressing save on the network information, make a note of the devicename that is shown on the screen, this will be the name that is used 
in the next step to access the configuration pages. The link would look like this: **http://kegmon56EA34.local**

Under wifi settings you can define a primary and secondary wifi SSID. The secondary will be used in case the primary fails. If the secondary is 
successful then it will be used as primary. *The second wifi setting is optional and not needed.*

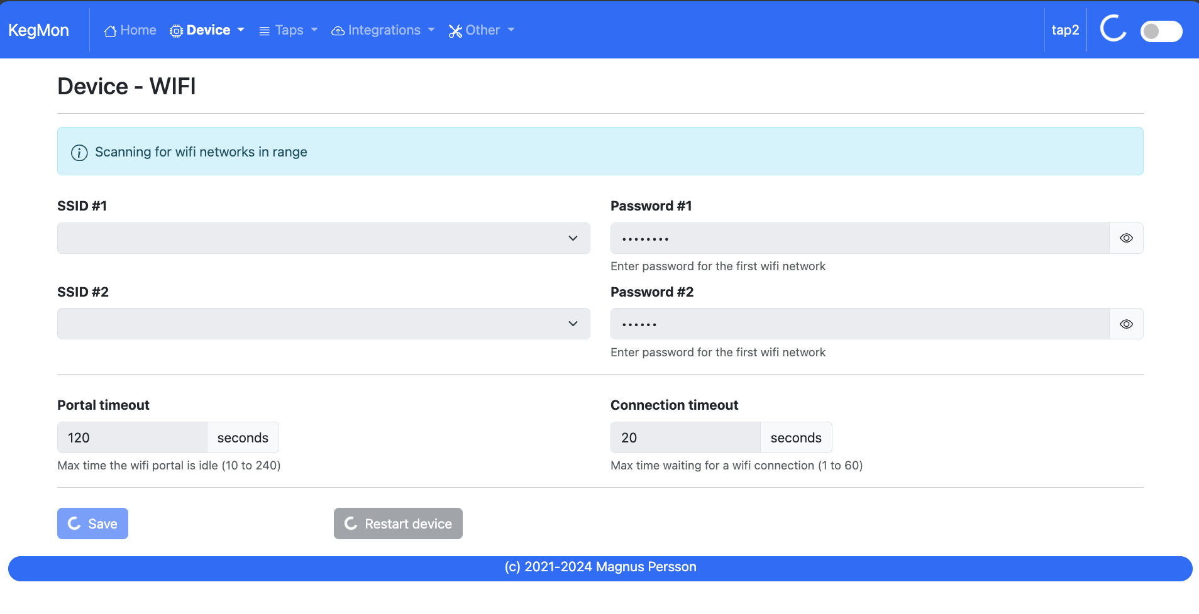
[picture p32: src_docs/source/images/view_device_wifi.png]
Wifi page


.. _setup_ip:

Finding the device adress
=========================

Once the wifi network settings have been added then the device will reboot and connect to your network. If the blue led is flashing then it's up and running and is ready to be configured. 

If your computer supports mDNS the address you saw before can be used in your web browser to connect to the device. Windows does not have the best support for mDNS so if you are having issues 
with finding the network name you can try the following:

* Check your wireless router for the IP address and use that to connect instead, for example; http://192.168.1.56
* Download an IP scanner / Port Scanner on your Windows computer or mobile device and use that to find what devices are listening on port 80.

Once you can access the user interface then proceed to the next step.

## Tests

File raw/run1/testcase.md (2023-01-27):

Based on testbed (RED base) under room conditions.

Simulated data based on removing:
* 33cl beer
* 66cl beer

Should result in:
* Pour detection of 33cl
* Pour detection of 66cl

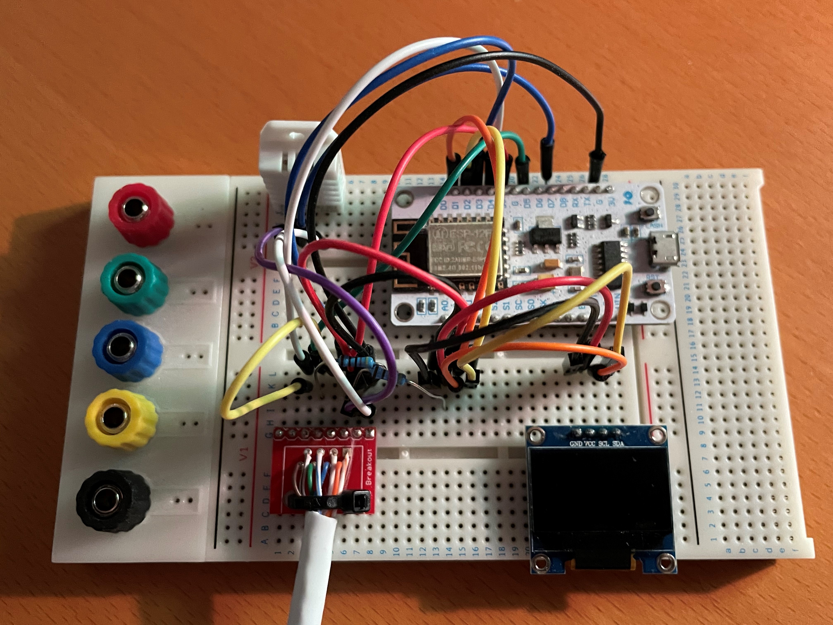
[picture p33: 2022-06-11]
src_docs/source/images/test.jpg

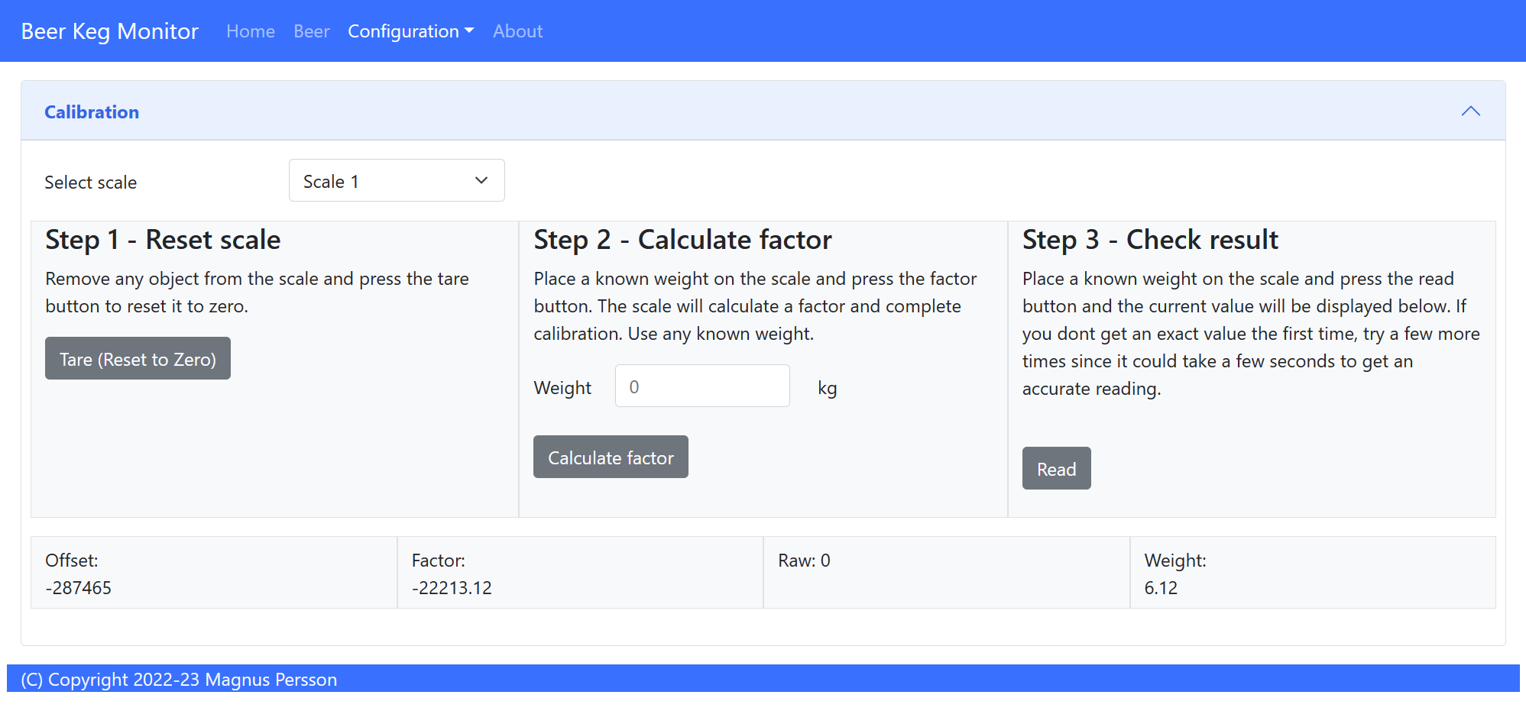
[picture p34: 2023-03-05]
src_docs/source/images/calibration.png

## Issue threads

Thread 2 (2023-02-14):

ESP32 upgrade?

darkside90a, 2023-02-14:
I've successfully built one from this project with a different solution of scale bases. Incredible stable, even with v0.5.0b7 installed. Deviations are just 0.06 and 0.04%.
ESP8266 web interface is a bit slow though. I'd love to see an ESP32 variant, for instance based on ESP32-S2.
As I built the case unit as plug-in modules on a 60x80 experiment PCB (#90664) from Kjell&Co, it's really easy to replace the ESP8266. The whole unit fits snugly into a 120x70x35 case (#89026) from Kjell&Co.
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

mp-se, 2023-02-14:
> I've successfully built one from this project with a different solution of scale bases. Incredible stable, even with v0.5.0b7 installed. Deviations are just 0.06 and 0.04%. ESP8266 web interface is a bit slow though. I'd love to see an ESP32 variant, for instance based on ESP32-S2. As I built the case unit as plug-in modules on a 60x80 experiment PCB (#90664) from Kjell&Co, it's really easy to replace the ESP8266. The whole unit fits snugly into a 120x70x35 case (#89026) from Kjell&Co.

Nice build. I've used some similar PCB for my builds, once I'm happy with the hardware design I will create a pcb. I have also created a 3d printable case for my board. It looks like the same size board that I used (but I bought mine from electrokit)

I've experience that I get more variation when the scale is in the keezer and the temperature varies. Have you noticed anything around that part ?

I know the Web UI is a little sluggish but I dont think a esp32s2 board would help. The main issue is that reading the scales takes approx 400 ms each so that loop is the problem since that would not be faster on an esp32.  So every read cycle (2 seconds) the CPU is blocked for 800 ms reading the scales.

I have been considering an esp32 but in that case it would be better with one that has more than one core like the older ESP32 D1 mini (that have 2 cores) or one of the development boards but then I loose the nice form factor. S2 and C3 only have one core each.  But it's not that hard to port this to a esp32 for testing at least. Will do that once I'm happy with the stability.

Another option is to move to a AsyncWebServer which would be much faster and I'm probably going that route once the functionallity is more stable. That option can cause real crashed and reboots if there are issues with the code (can be unstable) and is not that easy to develop and test.

Let me know if you are missing any features.

darkside90a, 2023-02-14:
Thanks, a good explanation for not switching to ESP32-S2/C3.

I had more variations when the scales were outside the keezer. Maybe because of a more uneven surface.
Could your issues be how the load sensors are mounted in the base?
My base is made of 7mm plywood. The load sensor feet are modified versions of thingiverse #309451. The interconnect lid as well.
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

I re-designed the "top" of the feet thicker + groove for a larger washer (M5x20).
Theoretically, load from the small notch on the load sensor is now spread over a larger area. The feet are really flexible too.
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

mp-se, 2023-02-14:
That's a really god case for the scales. I will have a look at those and see if I can modify my 3d model so they are not exposed as of today.

I will test out both options (async) and (esp32s2) to see what improvements can be made. I getting to a state where I think the basic function are in place so its the next natural step to look at performance improvements.

mp-se, 2023-02-14:
There is another option I will try as well, and that is a replacement for the HX711 board (sparkfun board) that uses i2c instead that should be much faster to get data from.

darkside90a, 2023-02-15:
Another theory around scale varations:
Still using your flat Cat6, are you?
I am using a round UTP Cat6 (Kjell&Co #39847).
Could your flat Cat6 be affected by EMI?
According to Sparkfun, YLW (= Ground, like BLK) on HX711 could be connected to the shield in one end of a shielded Cat6 to reduce EMI.
Unfortunately, that kind of cable would be much stiffer.
Maybe connecting the unused Brown/White to YLW reduces EMI as well?

mp-se, 2023-02-15:
Yes, im using unshielded cat6 (flat) and i dont have interference outside the keezer. So my therory is that tempersture and compressor is causing the drift/interference. Its not a big deal  so it might not be worth to fix…. But it could be worth to test just to know for sure

mp-se, 2023-02-16:
I've added a firmware_async.bin that you can try out (dev stream). This moves to an async webserver with better response. Let me know what you think.

darkside90a, 2023-02-16:
Tried installing beta9 and beta10 (the async one) via web interface . After 15-20 seconds they both loop back to web portal mode. I also noticed none of them detected the temp sensor during boot.
What I did not try was installing beta9 or 10 from scratch, wiping flash first.

Uptime was long enough for me to reinstall the working beta7, which correctly detects both scales and tempsensor after a cold start.

I managed to catch a raw transcript via USB/minicom when running beta10 if that is of any help:

[202302161535.txt](https://github.com/mp-se/kegmon/files/10757204/202302161535.txt)

mp-se, 2023-02-16:
Thanks, i will take a look later, i have not done any extensive testing och those builds.

mp-se, 2023-02-17:
Found the issue, I need to refactor some code so I don't call hardware/IO from the webserver, this is causing the device to crash.

I just did a couple of quick tests without any scale so I didnt see the problem.

mp-se, 2023-02-17:
Think i fixed the issue b11 in the dev branch

mp-se, 2023-02-18:
I had to refactor quite some code in order to make this work without issues. I have released a v0.5 now that I have tested the basic functions and calibration flow. That seams to work fine with the async option. I will upgrade my own keezer to this version and start to see if I can find any more issues. Thanks for the input. I will use this to improve the documentation when I have some time.

darkside90a, 2023-02-18:
Installed 0.5.0 async now.
Had to finish off calibration of 3x Gravitymon  v1.3.0-b1 units first :-)
Whow, massive speed improvement!
Temperature sensor was shown not detected during a cold boot. But temp/humidity seems to be correct in web interface.
MQTT telegrams are coming through via Mosquitto to HA as well.
Thank you!

mp-se, 2023-02-19:
Yes, the pins for scale 1 sometimes needs a hard reset to work. I have the same problems with the iSpindle and a soft reset and connection issues with the gyro. Have not found a solution around that other than doing a hard reset.

Yes, its much more responsive. The async webserver hooks into the internal delay/yield interrupts so it can serve data at any point without waiting for the loop. I'm moving that code to gravitymon as well to speed that up.

mp-se, 2023-03-03:
@darkside90a I've done most of the coding for an esp32s2 chip with sync/async support. Still need to do some more testing. Let me know if you want to test that version.

darkside90a, 2023-03-03:
Sure, I can do some testing.
As long as pin compatibility is still similar to the ESP8266, I can easily plug in an ESP32-S2 instead

mp-se, 2023-03-03:
It will be pin compatible, i will let you know when i have tested it

mp-se, 2023-03-05:
You can try the 0.6 beta 1 version for the esp32s2.

darkside90a, 2023-03-06:
Great work!
Flashed and plugged in ESP32-s2 this morning.
Responsive web interface! You cannot get it better, unless the HX711 is replaced with a much more expensive i2c amplifier, like the NAU7802 mentioned by LBussy.

I have only found one issue(?) so far:
Configuration --> History graph
gives:
"Failed to load level history from device"

For those not very familiar with esptool.py, I found this approach of first-time flashing to work too:
* Use Brewflasher to flash the ESP32-s2 device variant of Gravitymon
* Configure WiFi
* Connect to the Gravitymon web interface and go to Upload firmware.
* Upload Kegmon ESP32-s2 beta binary firmware and reboot

Initially I tried to upgrade the ESP8266 D1 Mini from 0.5.0 to 0.6.0b1 when it was still in place. Because then I could do a backup, copy data over to the ESP32-s2 backup, and restore. No new calibration needed.
I made a new attempt when the D1 Mini was not connected to the circuit.
Success! No idea why.

mp-se, 2023-03-07:
Thanks. I will try the NAU7802 chips as well, I have 2 of them.

The problem with the history graph is probably related to that you dont have any data logged if you switched the board. But I will check to confirm that.

I can confirm that uploading from the 0.5 version didnt work but I found one issue when testing the esp32 async that I fixed, could be that problem that causes it to fail (I guess you used the async 0.5).

I will add the firmware to brewflasher once I have tested it a little more and fixed the main issues.

darkside90a, 2023-03-07:
Yes, async 0.5 on the ESP8266 D1 Mini.
If you are curious, here are my stability statistics so far with the ESP32-s2:
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

mp-se, 2023-03-07:
Found the issue with the update. The main problem is that the device does not reboot when firmware has been uploaded. I flashed and then did a manual reset and when it reboots it will switch to the new version. Applies to the 0.5 async version. Will check if I managed to fix this in the 0.6 version.

Really nice statistics. Seams really stable.

mp-se, 2023-03-08:
Closing this for now, reopen if needed.

ribbonofblack, 2023-03-18:
Hi Darkside, your covers for the load cells and wiring look slick. Do you mind sharing the stl's for them?

darkside90a, 2023-03-18:
Hi,
Sure, no problems. I have uploaded the stl's to my github repo:
  github.com/darkside90a/kegmon-base
I also added a short description and some pictures

mp-se, 2023-03-18:
Nice work, I will add a link to your repo in the documentation so its easy to find.

ribbonofblack, 2023-03-19:
Great, thanks!

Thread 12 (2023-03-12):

DHT22 sensor not working with ESP32S2

mp-se, 2023-03-12:
The DHT22 sensor is not detected when using an ESP32S2 board. Works fine on ESP8266.

Adding pull-up resistor does not help. Connecting the DHT22 power directly to +3.3V works but if the sensor stops working then you need to power on/off the device.

For the ESP32S2 I currently recommend to use the DS18B20 sensor instead.

mp-se, 2023-03-18:
Change the schema to drive the DHT22 on 5V via a transistor to ensure we have enough power.

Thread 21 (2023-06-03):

Add device info to hass integration

mp-se, 2023-06-03:
Add device information so the sensors are grouped into one device

lbussy, 2023-06-09:
This sounds familiar, will be monitoring. :)

mp-se, 2023-06-19:
Added to dev branch

Closed 2023-06-19.

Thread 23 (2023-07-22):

Not detecting scales until serial monitor is connected

whywouldi, 2023-07-22:
When starting up ESP-8266 or after re-booting the scales are not detected.

If I start serial monitor on laptop and re-boot the ESP-8266 the scales are detected and everything works ok.

mp-se, 2023-07-22:
That is strange, i have never had that issue. Could it be a power adapter issue ? How do you power the device ?

whywouldi, 2023-07-23:
Agreed it is a weird one. I'm currently powering via the micro-usb via either laptop or PSU. I have found powering by Micro-USB with my brewpiless keeps things more stable than via 3v3 or 5v.

The condition is totally repeatable.

mp-se, 2023-07-23:
What board are you using? Have you tested with another esp? I dont think this is software related

whywouldi, 2023-07-23:
I'm using the D1-mini. I will flash another board and report back in a day or so.

Much appreciate the guidance and the project is outstanding cheers.

mp-se, 2023-07-23:
Which hx board are you using, green, red or purple?

whywouldi, 2023-07-23:
Its the green HX711. I have a few of these too so will replace both boards and see if that fixes it.

whywouldi, 2023-07-29:
I have created a new circuit board so I can change out the D1 mini and HX711. Have tried to boards of each and the same thing. Stumped.

I will keep paying with now I have a better setup and report back if I get it going.

mp-se, 2023-07-29:
Ok, i can see if i can replicate the issue with a green board

mp-se, 2023-07-31:
I have a firmware that I use to the sensors and the hardware setup. You could install this on an esp8266 and see what the result is. I will just display the raw values on the 1st OLED screen. If you want to build it via platformIO its the hardware target. This could be extended to help check for hardware issues.

[hw_firmware.zip](https://github.com/mp-se/kegmon/files/12212370/hw_firmware.zip)

whywouldi, 2023-07-31:
Again thanks so much for your time and help.

I have flashed the Bin file to the ESP8266:
Display show temp with live data, Scale 1 is 0, Scale 2 is 0, Raw 1 is 0 Raw 2 is 0.

After a few minutes I started serial monitor and within 5 seconds the scale 1 starts to read a value along with the temp. All others remain at 0.

This is repeatable.

whywouldi, 2023-07-31:
May have just found an article that could explain it?

https://www.esp8266.com/viewtopic.php?p=53827

I am using D3 as the data connection to the HX711. Will have to solder up a new board to try on the "scale 2 input" but unsure if that would work with the detail on the site (only one scale can be used with esp8266).

mp-se, 2023-07-31:
If you use the hx711 you can use 2 scales without probleme on esp8266, its the i2c based adc that is limited to one since the esp8266 only supports one i2c bus.

mp-se, 2023-07-31:
Can you upload a picture of your esp board? Back and front.

mp-se, 2023-07-31:
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

I dont think this is related. If this is the case it would not boot at all. You could try to add a 3k resistor between d3 and 3v as a test. You could do the same with d4 as well. This shoudl force it to be high and not trigger the boot mode.

whywouldi, 2023-07-31:
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

whywouldi, 2023-07-31:
These are the two types but I have tried a couple of the v3 boards. All doing the same.

I currently have a 4k7 across D3 and 3v3. I’ve tried 4k7 across just data and data + clock all making no difference. Also good to know about two scales using the hx711 thanks.

mp-se, 2023-08-03:
I've tried to replicate your problem but on my test build it works fine- I've tested with external power supply to the 5V and both the purple and green HX boards. It boots fine and reads the data as it should

Let me know how your tests are progressing

whywouldi, 2023-08-03:
I am stumped. I Will continue to try different things and see if I can get it going.

I’m now heading out of the UK for a few weeks so will not make any progress for a while. I will report back though should I manage to sort it or fail and give up (unlikely).

As always I appreciate you taking the time to help.

cheers,

mp-se, 2023-08-03:
Do you have an esp32 s2 mini to see if that works better ?

whywouldi, 2023-08-27:
Hi, back from my vacation and I've spent this morning using a breadboard to aid testing. Following on from the gpio0 (D3) link I decided to move the scale to gpio15 (D8) & gpio14 (D5) and it was recognised. It calibrates and functions correctly every time.

Is it possible to alter the code to move scale one to D8/D5 and scale two to D3/D4? Would this be a lot of work or just on the inital pin setup?

I dont have an ESP32 I'm afraid but I might have to get one.

mp-se, 2023-08-28:
Yes you can alter the pins in the main.hpp file and then compile your own version.

Just make sure that you dont use the same pins for several functions.

mp-se, 2023-08-31:
Try this build, https://github.com/mp-se/kegmon/blob/dev/bin/firmware.bin

You can change pin config in the web ui. you need to reboot for it to take effect. I have just done some simple testing...

whywouldi, 2023-09-02:
Thanks so much for updating the .bin in such a short time.

I have been working with the new .bin all morning and I keep getting the same issue. when I go to the config page I get the error "unable to get data from the device". every other page works ok just the config page. Other symptoms are no detail in the new drop down boxes and inability to save with the error "Invalid ID".

I've now tried this on the original three chip and two brand new chips purchased in the hope of resolving things (all wemos D1 mini's). Note that when testing the new chips I have not connected anything to them and not even soldered the pins on the board yet the error is repeated.

sorry for the continued issues.

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

mp-se, 2023-09-02:
I know what the problem is, will fix it later today when im at a computer

mp-se, 2023-09-02:
I've checked in the fix, should be ready in a few minutes when the buiid has been completed

whywouldi, 2023-09-02:
Just uploaded, altered the pin setting, calibrated and tested. Everything is working perfectly!

Thank you so much for all the effort and time you've spent. Absolute legend.

Closed 2023-09-02.

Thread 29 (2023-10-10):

TempSensorBase has no virtual destructor, causing memory leak of no temperature sensor connected

caswal, 2023-10-10:
Thanks for KegMon is a great project, I have been modifying to add support for 3 and 4 Scales.

temp_base.hpp is missing a virtual destructor, therefore TempSensorDS and TempSensorDHT are not getting their destructors called on the std::unique_ptr reset in TempSensorManager::setup()
This causes about a 100-byte memory leak for TempSensorDS per attempted setup cycle if no temperature sensor is connected.

My work in progress fork with my 3/4 scales changes are here: https://github.com/caswal/kegmon/tree/4_Scale

In short, I added a scale_count = x to [common_env_data] in platform.io

This enables various #if CFG_SCALECOUNT > 2 etc macros to enable more scale logic.
It also uses scale_count  with a python script to then move different htm files from the sub 2/3/4 folders to /html and minimize them.

I don't have any displays yet, so haven't done anything in regards to that, annoyingly on my custom PCB's, the community  OLED 0.96" Component I used, had the VCC and GND Nets swapped on the footprint. So need to get some new ones made.

mp-se, 2023-10-10:
Thanks, i will fix that. Good find

mp-se, 2023-12-15:
Fixed in dev

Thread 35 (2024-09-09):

Add ability to push data to Barhelper

wookienow, 2024-09-09:
Add the ability to push data to Barhelper for Taplist display
https://barhelper.no/

mp-se, 2024-09-09:
Do you have any documentation on how there API's looks like ? I could not find anything useful on the URL you shared.

Normally this should not be a big change to add.

mp-se, 2024-09-09:
Found the details in the docs.... Will give it a try

mp-se, 2024-09-09:
There are apparently 2 ways to report data, either the current volume or the detected pour volume... which is to prefer?

mp-se, 2024-09-09:
You can try this version here; https://github.com/mp-se/kegmon/tree/dev/bin

It updates the volume in Barhelper once there is a stable level. This seamed to be the best option to secure the level is accurate.

wookienow, 2024-09-09:
Amazing. Will try the binary tonight.

wookienow, 2024-09-10:
@mp-se I have had a go. I can see in the log when weights change publishing to MQTT and this is working. I  have configured the Barhelper API key but I am not seeing anything in the logs saying it is trying to publish to barhelper. Or anything in barhelper. It looks like it should log in the console in the barhelper.cpp code.
Any idea what else I could try? Will it work with both configured?

mp-se, 2024-09-10:
You will get a printout in the serial log when sending data to barhelper, and also the response. Unfortunately the response is not a real json (they have made a misstake) so i cannot parse and check the return. I have reported that problem to the author so we will have to see if they fix that.

You basically just need to enter the API KEY and have a name for the taps.  The integration will not work without the API KEY.

Data will be posted when there is a stable level and if there is no defined Custom Keg Monitor it will be created. You then need to connect that to a tap/keg.

mp-se, 2024-09-10:
You can try the new build in the dev branch, it how will show the current status of the transmissions on the main page

mp-se, 2024-09-11:
The pins are configurable under hardware

wookienow, 2024-09-11:
I am getting this error. I am able to call the API directly and it works with the same key externally.
Any ideas.

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

mp-se, 2024-09-11:
-1 means "connection refused" so do you have a firewall that blocks the request ?

wookienow, 2024-09-11:
No. Nothing blocking the call. I am calling the API directly from a laptop
on the same network.

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

wookienow, 2024-09-11:
Happy to share my API key as well to see if you get the same error as I can always recreate.

mp-se, 2024-09-11:
Can you see what the output from the serial log is? That should give some more details

mp-se, 2024-09-11:
Are you using an esp8266 or esp32? Ssl could cause issues on the esp8266 due to lack of memory

wookienow, 2024-09-11:
Logs appear to be getting cut off but this is what is shown (2 examples below)

` 953097 I: HA  : Sending POUR information to HA, pour 0.52l [0].
    953101 I: TPL : Buffer needed 390.
    953217 I: LVL : Logging level change    953245 I: TPL : Buffer needed 507.
    953339 I: PUSH: MQTT publish success    953397 I: HA  : Sending TAP informat    953442 I: PUSH: Sending values to mq    953521 I: BARH: Sending TAP informat    953663 I: PUSH: Adding header 'Content-Type': 'application/json'
    953664 I: PUSH: Adding header 'Autho    953694 E: PUSH: HTTP post failed, re    955078 I: LOOP: Reading data raw1=0.47,raw2=0.00,stable1=0.46, stable2=0.00,pour1=0.52,pour2=nan
    `
```

`53097 I: HA  : Sending POUR information to HA, pour 0.52l [0].
    953101 I: TPL : Buffer needed 390.
    953217 I: LVL : Logging level change    953245 I: TPL : Buffer needed 507.
    953339 I: PUSH: MQTT publish success    953397 I: HA  : Sending TAP informat    953442 I: PUSH: Sending values to mq    953521 I: BARH: Sending TAP informat    953663 I: PUSH: Adding header 'Content-Type': 'application/json'
    953664 I: PUSH: Adding header 'Autho    953694 E: PUSH: HTTP post failed, re    955078 I: LOOP: Reading data raw1=0.47,raw2=0.00,stable1=0.46, stable2=0.00,pour1=0.52,pour2=nan
```

wookienow, 2024-09-11:
Wemos D1 Mini 8266

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

mp-se, 2024-09-11:
Can you check how much free memory you have on the dashboard ?

mp-se, 2024-09-11:
Then its a memory problem. SSL requires 22kb free memory to work. You need an esp32s3 or esp32s2 mini for that to work

wookienow, 2024-09-11:
Thanks, I have 1 floating around will change it over and check but will be
tomorrow. Do you think there would be anything I could remove from the
codebase to free up memory so I don't have to replace it in all my scales?

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

mp-se, 2024-09-11:
You can try to run it without having any interaction with the UI that would help. The webserver and the api communication will consume quite a lot of memory. You can check the memory usage by accessing the http://deviceid/api/status that will give the raw json data. If that has more than 22kb memory free than it should work to update via ssl.

mp-se, 2024-09-11:
On my other projects only allow for SSL when the webserver is not used so that there is enough memory to run.... but remove the webserver would make it difficult to manage the configuration....

mp-se, 2024-09-11:
I just tested to call the API without SSL and that worked. I could change the code so on esp8266 it does not use SSL when calling barhelper, that could fix the problem. Not sure how long they will allow that....

wookienow, 2024-09-11:
I am willing to give it a go. Not using the web access didn't free up any memory. Not sure if it loads even if it isn't being accessed.

mp-se, 2024-09-11:
I will do the change after work and let you know when there is a new build to test

wookienow, 2024-09-11:
Tested this morning before work and seems to work now. Looks like you
nailed the reason why. Will do some more testing tonight but that is for
all the effort and the quick response.

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

wookienow, 2024-09-13:
This works really well and data now flowing through.
Would be great if in the future it supported SSL as well but understand the mem requirements.
I found one other minor issue when configuring and have another enhancement request I will log these seprately.

Closed 2024-09-13.

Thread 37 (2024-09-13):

Now Pouring or Scale Unstable Flag

wookienow, 2024-09-13:
I would love to be able to trigger events in Home Assistant when a pour starts vs waiting for the scale to become stable.
I love the fact it doesn't consistently send scale readings while it stabilizes but would be good if the was a boolean flag the gets turned on when scales goes outside a range say 25g and then turns off when it goes stable again (basically when the scale weight is sent now)

Ideally this is sent to home assistant when it gets turned on straight away and then again when turned off with the new weight in the same message

Understandably as described in the docs this may not get turned off when multiple pours occur in a row.

Not fussed what it is called. Scale Unstable or Beer Pouring or something else.

My aim for this is to run some LED lights and sounds on my kegerator when pouring and take am image of the person pouring at the time. Won't be perfect due to the double pour but will capture most of the time and lights will still work either way.

Not sure if this helps you or anyone else but thought it may.

mp-se, 2024-09-16:
Its a good idea but with the HX711 and the load cells I dont think this will be possible. The loadcells are not that accurate and they will fluctuate quite a lot. It takes 8-10 seconds for the scale to detect a possible change in level, so before a new level is established it can take up to 30 seconds or more. Currently I ignore any change less than 100g since that is how much it can fluctuate... You will get spikes that are much higher so in order to detect the level you need to get avearage readings over a long time period..

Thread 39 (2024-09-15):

Pass Tap Settings to home assistant

wookienow, 2024-09-15:
t's good to have the remaining amount and glasses in Home assistant but it would be also good to pass through the current configured data for the tap
Keg Size
Empty Keg Weight
Glass Size.

This would allow percentage calculations to be done to show % remaining as well as show a different image based on keg size.

As an alternate passing through % remaining in the keg based on the keg config would also work along with glasses and remaining.

This email and any attachments are confidential and must not be disclosed to any person other than the intended recipient.

mp-se, 2024-09-16:
Good idea, i will see how to best implement that.

mp-se, 2024-09-28:
I suggest that keg volume and glass volume are added as attributes to the volume data.

Currently the volume in (liters) is the state and { "glasses": 1 } is the attribute. If I extend the attribute to contain { "glass_volume": 1, "keg_volume": 1 } both in liters you can do the calculation. I can also add "keg_percentage": 1 as an attribute so you dont need to calculate that.

Dont really understand why you need the keg weight since this is not really usable ?

mp-se, 2024-09-29:
You can try the build in the dev branch, it should have the requested params. This is an example from my install:

{"glasses":31.2,"keg_volume":19.00,"glass_volume":0.40,"keg_percent":65.59}

Closed 2024-09-30.

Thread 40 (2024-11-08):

Co2

Piilukirves, 2024-11-08:
Is It possible to add co2 profile?
Using single loadcell to measure amount of co2?
Sodastream bottle or small co2 bottle?

mp-se, 2024-11-09:
Can you elaborate on how you would want this to work?

Piilukirves, 2024-11-12:
Is It possible to use third scale via relay on same channel as one of the kegs? And check the co2 level? Like once a minute or so? Co2 consumption is not so crusial but just to see the level.

mp-se, 2024-11-12:
It's not possible to add more scales with the current hardware/software design. In the future that might be an options when I have time to do a redesign of the hardware and software. I would need a different esp board with more pins and more processing power / more cores.

I'm not sure that you would get any good readings on measuring so small weights, the loadcells are not that accurate...

mp-se, 2025-01-13:
Closing this since there is no new feedback

Closed 2025-01-13.

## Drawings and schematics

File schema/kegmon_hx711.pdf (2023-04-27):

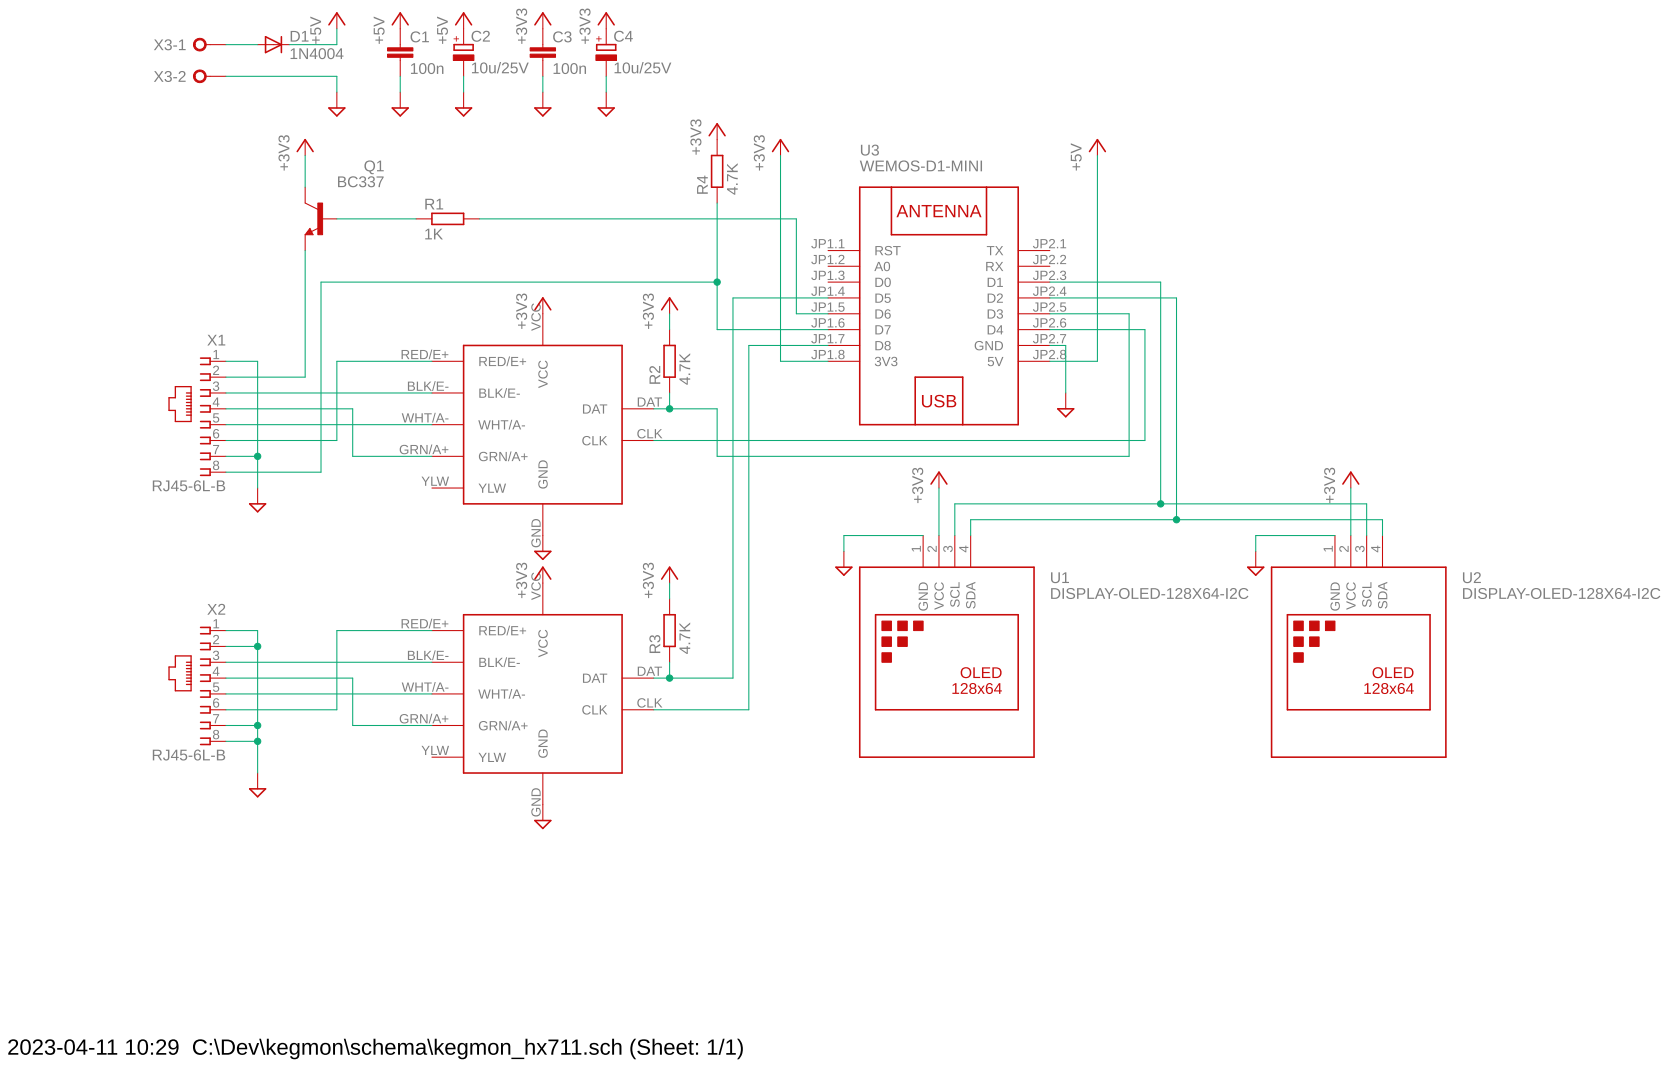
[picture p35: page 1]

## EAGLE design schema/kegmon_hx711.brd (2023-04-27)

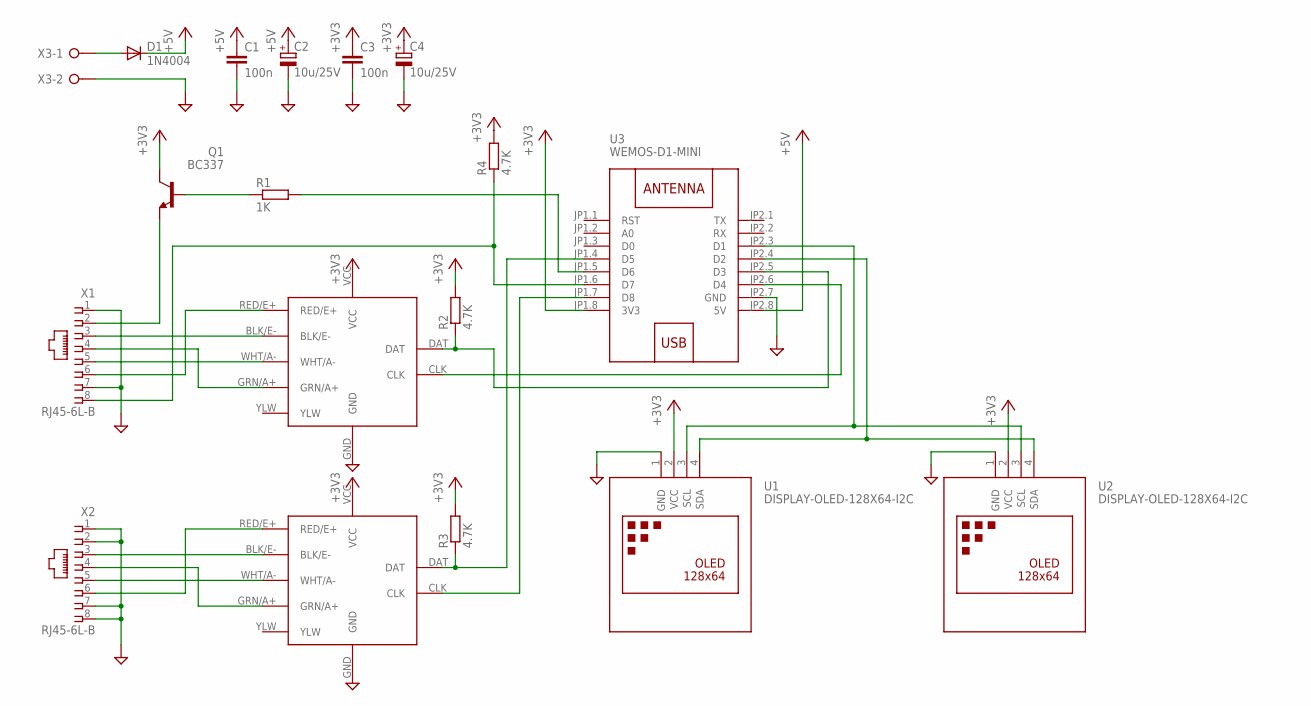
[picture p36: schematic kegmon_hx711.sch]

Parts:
C1, C3: 100n; C050-025X075
C2, C4: 10u/25V; E2,5-5
D1: 1N4004; DO41-10
IC1, IC2: SPARKFUN-HX711
Q1: BC337; TO92
R1: 1K; 0207/10
R2, R3, R4: 4.7K; 0207/10
U1, U2: DISPLAY-OLED-128X64-I2C; DISPLAY-OLED-128X64-I2C-NOHOLES
U3: WEMOS-D1-MINI
X1, X2: RJ45-6L-B; RJ45-NO-SHIELD
X3: W237-02P; W237-132

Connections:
+3V3: C3.1, C4.+, IC1.VCC, IC2.VCC, Q1.3 (C), R2.2, R3.2, R4.2, U1.2 (VCC), U2.2 (VCC), U3.JP1.8 (3V3)
+5V: C1.1, C2.+, D1.C, U3.JP2.8 (5V)
GND: C1.2, C2.-, C3.2, C4.-, IC1.GND, IC2.GND, U1.1 (GND), U2.1 (GND), U3.JP2.7 (GND), X1.1, X1.7, X2.1, X2.2, X2.7, X2.8, X3.2
unnamed: Q1.2 (B), R1.1
unnamed: U1.3 (SCL), U2.3 (SCL), U3.JP2.3 (D1)
unnamed: D1.A, X3.1
unnamed: IC1.RED/E+, X1.6
unnamed: IC1.BLK/E-, X1.3
unnamed: R4.1, U3.JP1.6 (D7), X1.8
unnamed: IC1.WHT/A-, X1.5
unnamed: IC1.GRN/A+, X1.4
unnamed: IC2.BLK/E-, X2.3
unnamed: IC2.RED/E+, X2.6
unnamed: IC2.GRN/A+, X2.4
unnamed: IC2.WHT/A-, X2.5
unnamed: IC1.DAT, R2.1, U3.JP2.5 (D3)
unnamed: IC1.CLK, U3.JP2.6 (D4)
unnamed: IC2.DAT, R3.1, U3.JP1.4 (D5)
unnamed: IC2.CLK, U3.JP1.7 (D8)
unnamed: U1.4 (SDA), U2.4 (SDA), U3.JP2.4 (D2)
unnamed: Q1.1 (E), X1.2
unnamed: R1.2, U3.JP1.5 (D6)

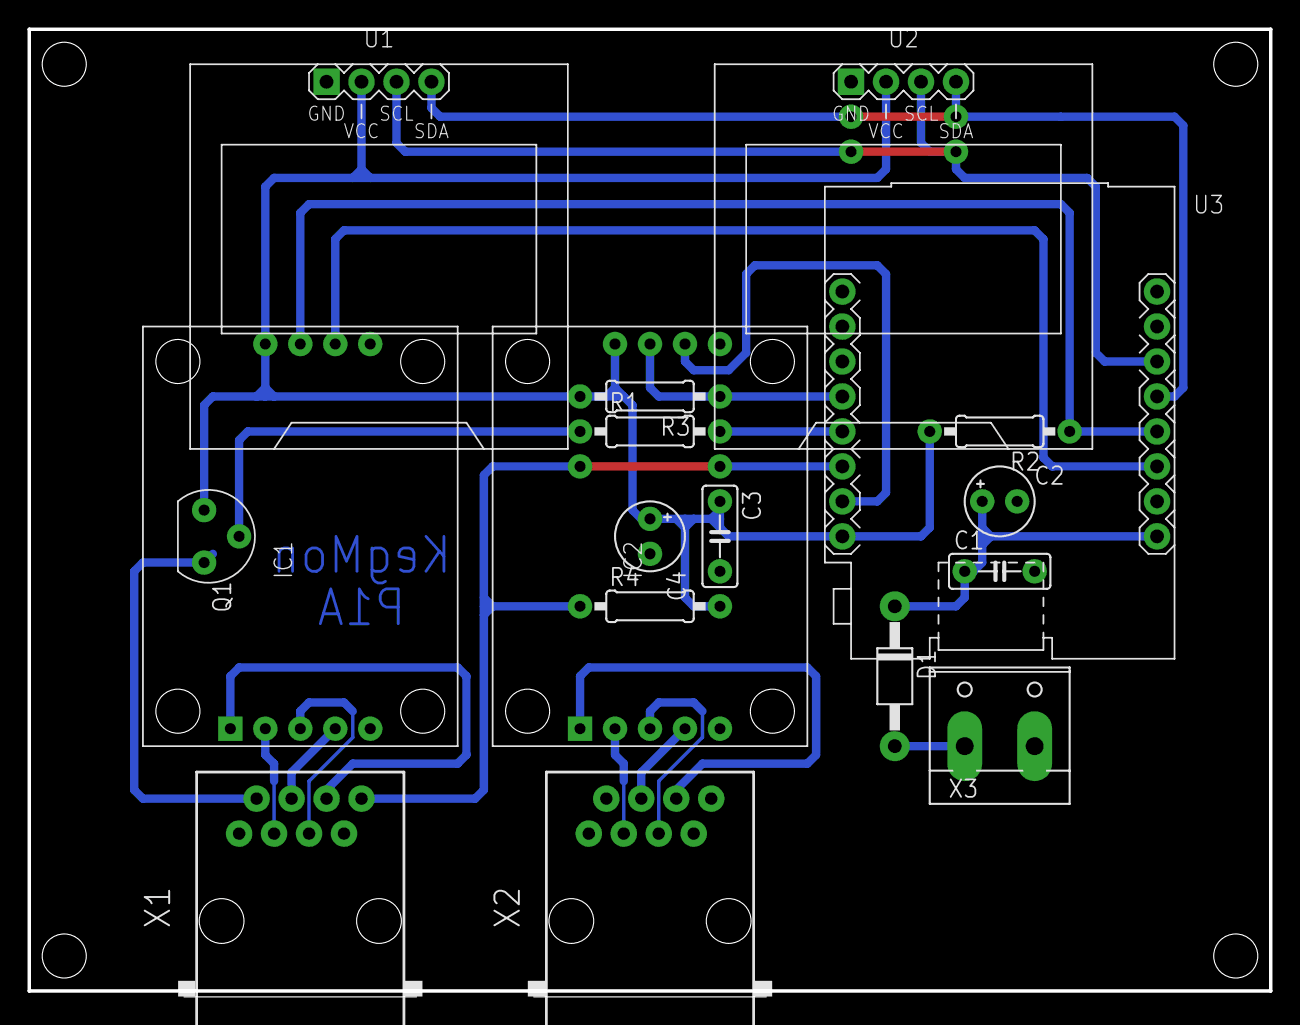
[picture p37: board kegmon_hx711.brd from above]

Board: 2 copper layers, 90.2 x 69.8 mm, 18 parts (0 on the bottom side), 22 nets.

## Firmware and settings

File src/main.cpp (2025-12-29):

/*
MIT License

Copyright (c) 2022-2024 Magnus

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
THE SOFTWARE IS PROVIDED "AS IS", WITHOUT WARRANTY OF ANY KIND, EXPRESS OR
IMPLIED, INCLUDING BUT NOT LIMITED TO THE WARRANTIES OF MERCHANTABILITY,
FITNESS FOR A PARTICULAR PURPOSE AND NONINFRINGEMENT. IN NO EVENT SHALL THE
AUTHORS OR COPYRIGHT HOLDERS BE LIABLE FOR ANY CLAIM, DAMAGES OR OTHER
LIABILITY, WHETHER IN AN ACTION OF CONTRACT, TORT OR OTHERWISE, ARISING FROM,
OUT OF OR IN CONNECTION WITH THE SOFTWARE OR THE USE OR OTHER DEALINGS IN THE
SOFTWARE.
 */
#include <display.hpp>
#include <displayout.hpp>
#include <kegconfig.hpp>
#include <kegpush.hpp>
#include <kegwebhandler.hpp>
#include <main.hpp>
#include <ota.hpp>
#include <perf.hpp>
#include <scale.hpp>
#include <serialws.hpp>
#include <temp_mgr.hpp>
#include <uptime.hpp>
#include <utils.hpp>
#include <wificonnection.hpp>
#if CONFIG_IDF_TARGET_ESP32S2
#include <esp32s2/rom/rtc.h>
#endif
#if CONFIG_IDF_TARGET_ESP32S3

#include <esp32s3/rom/rtc.h>
#endif
#if defined(ESP32)
#include <esp_core_dump.h>
#endif

#include <cstdio>

SerialDebug mySerial(115200L);
KegConfig myConfig(CFG_MDNSNAME, CFG_FILENAME);
WifiConnection myWifi(&myConfig, CFG_APPNAME, "password", CFG_MDNSNAME);
OtaUpdate myOta(&myConfig, CFG_APPVER);
KegWebHandler myWebHandler(&myConfig);
KegPushHandler myPush(&myConfig);
Display myDisplay;
Scale myScale;
LevelDetection myLevelDetection;
TempSensorManager myTemp;
SerialWebSocket mySerialWebSocket;
DisplayLayout myDisplayLayout;

const int loopInterval = 2000;
int loopCounter = 0;
uint32_t loopMillis = 0;

RunMode runMode = RunMode::normalMode;

void scanI2C(int sda, int scl);
void logStartup();
void checkCoreDump();

void setup() {
#if defined(PERF_ENABLE)
  PerfLogging perf;
  perf.getInstance().setBaseConfig(&myConfig);
#endif

  PERF_BEGIN("setup");
#if defined(ESP8266)
  Log.notice(F("Main: Reset reason %s." CR), ESP.getResetInfo().c_str());
  Log.notice(F("Main: Started setup for %s." CR),
             String(ESP.getChipId(), HEX).c_str());
#else
  // see: rtc.h for reset reasons
  Log.notice(F("Main: Reset reason %d." CR), rtc_get_reset_reason(0));
  Log.notice(F("Core dump check %d." CR), esp_core_dump_image_check());

  char cbuf[30];
  uint32_t chipId = 0;
  for (int i = 0; i < 17; i = i + 8) {
    chipId |= ((ESP.getEfuseMac() >> (40 - i)) & 0xff) << i;
  }
  snprintf(&cbuf[0], sizeof(cbuf), "%6x", chipId);
  Log.notice(F("Main: Started setup for %s." CR), &cbuf[0]);
#endif
  Log.notice(F("Main: Build options: %s (%s) LOGLEVEL %d " CR), CFG_APPVER,
             CFG_GITREV, LOG_LEVEL);

  myConfig.checkFileSystem();
  myConfig.migrateSettings();

  PERF_BEGIN("setup-config");
  myConfig.loadFile();
  PERF_END("setup-config");
  myConfig.setWifiScanAP(true);

  delay(4000);

  Log.notice(F("Main: Initializing I2C bus #1 on pins SDA=%d, SCL=%d" CR),
             myConfig.getPinDisplayData(), myConfig.getPinDisplayClock());
#if defined(ESP8266)
  Wire.begin(myConfig.getPinDisplayData(), myConfig.getPinDisplayClock());
#else  // ESP32
  Wire.setPins(myConfig.getPinDisplayData(), myConfig.getPinDisplayClock());
  Wire.begin();
#endif
  Wire.setClock(400000);
#if !defined(ESP8266)
  Log.notice(F("Main: I2C bus clock=%d" CR), Wire.getClock());
#endif
  scanI2C(myConfig.getPinDisplayData(), myConfig.getPinDisplayClock());

  PERF_BEGIN("setup-display");
  myDisplay.setup();
  PERF_END("setup-display");
  PERF_BEGIN("setup-wifi");
  myWifi.init();
  PERF_END("setup-wifi");

  delay(200);

  PERF_BEGIN("setup-scale");
  myScale.setup();
  PERF_END("setup-scale");

#if defined(ESP8266)
  ESP.wdtDisable();
  ESP.wdtEnable(5000);
#endif

  // No stored config, move to portal
  if (!myWifi.hasConfig() || myWifi.isDoubleResetDetected()) {
    Log.notice(
        F("Main: Missing wifi config or double reset detected, entering wifi "
          "setup." CR));
    myDisplayLayout.showWifiPortal();
    myWifi.enableImprov(true);
    myWifi.startAP();
    runMode = RunMode::wifiSetupMode;
  }

  switch (runMode) {
    case RunMode::normalMode:
      PERF_BEGIN("setup-wifi-connect");
      myWifi.connect();
      PERF_END("setup-wifi-connect");
      PERF_BEGIN("setup-timesync");
      myWifi.timeSync();
      PERF_END("setup-timesync");
      break;

    case RunMode::wifiSetupMode:
      break;
  }

  checkCoreDump();

  PERF_BEGIN("setup-webserver");
  myWebHandler.setupWebServer();
  mySerialWebSocket.begin(myWebHandler.getWebServer(), &EspSerial);
  mySerial.begin(&mySerialWebSocket);
  PERF_END("setup-webserver");

  PERF_BEGIN("setup-temp");
  myTemp.setup();
  PERF_END("setup-temp");

  Log.notice(F("Main: Setup completed." CR));
  myDisplayLayout.showStartupDevices(myScale.isConnected(UnitIndex::U1),
                                     myScale.isConnected(UnitIndex::U2),
                                     !isnan(myTemp.getLastTempC()));

  PERF_END("main-setup");
  PERF_PUSH();
  myTemp.read();
  delay(3000);
}

void loop() {
  if (!myWifi.isConnected() && runMode == RunMode::normalMode) myWifi.connect();

  myUptime.calculate();
  myWebHandler.loop();
  myWifi.loop();
  mySerialWebSocket.loop();
  myScale.loop(UnitIndex::U1);
  myScale.loop(UnitIndex::U2);

  if (abs(static_cast<int32_t>((millis() - loopMillis))) >
      loopInterval) {  // 2 seconds loop interval
    loopMillis = millis();
    loopCounter++;

    // Send updates to push targets at regular intervals (300 seconds / 5min)
    if (!(loopCounter % 300)) {
      Log.info(F("LOOP: Pushing updates to configured targets." CR));

      myPush.pushTempInformation(myTemp.getLastTempC(), true);

      if (myLevelDetection.hasStableWeight(UnitIndex::U1))
        myPush.pushKegInformation(
            UnitIndex::U1, myLevelDetection.getBeerStableVolume(UnitIndex::U1),
            myLevelDetection.getPourVolume(UnitIndex::U1),
            myLevelDetection.getNoStableGlasses(UnitIndex::U1), true);

      if (myLevelDetection.hasStableWeight(UnitIndex::U2))
        myPush.pushKegInformation(
            UnitIndex::U2, myLevelDetection.getBeerStableVolume(UnitIndex::U2),
            myLevelDetection.getPourVolume(UnitIndex::U2),
            myLevelDetection.getNoStableGlasses(UnitIndex::U2), true);
    }

    // Try to reconnect to scales if they are missing (60 seconds)
    if (!(loopCounter % 30)) {
      if (!myScale.isConnected(UnitIndex::U1) ||
          !myScale.isConnected(UnitIndex::U2)) {
        myScale.setup();  // Try to reconnect to scale
      }
    }

    // Try to reconnect to scales if they are missing (60 seconds)
    if (!(loopCounter % 10)) {
      printHeap("Loop:");
    }

    // The temp sensor should not be read too often.
    if (!(loopCounter % 15)) {
      myTemp.read();
      Log.notice(F("LOOP: Reading temperature=%F,humidity=%F,pressure=%F" CR),
                 myTemp.getLastTempC(), myTemp.getLastPressure(),
                 myTemp.getLastPressure());
    }

    // Check if the temp sensor exist and try to reinitialize
    if (!(loopCounter % 10)) {
      if (!myTemp.hasSensor()) {
        myTemp.reset();
        myTemp.setup();
      }
    }

    // Read the scales, only once per loop
    float t = myTemp.getLastTempC();

    PERF_BEGIN("loop-scale-read1");
    myLevelDetection.update(UnitIndex::U1, myScale.read(UnitIndex::U1), t);
    PERF_END("loop-scale-read1");
    PERF_BEGIN("loop-scale-read2");
    myLevelDetection.update(UnitIndex::U2, myScale.read(UnitIndex::U2), t);
    PERF_END("loop-scale-read2");

    // Update screens
    PERF_BEGIN("loop-display-default");
    myDisplayLayout.loop();
    myDisplayLayout.showCurrent(
        UnitIndex::U1, myScale.isConnected(UnitIndex::U1),
        myLevelDetection.getBeerWeight(UnitIndex::U1, LevelDetectionType::RAW),
        myLevelDetection.getBeerVolume(UnitIndex::U1, LevelDetectionType::RAW),
        myLevelDetection.getNoGlasses(UnitIndex::U1, LevelDetectionType::STATS),
        myLevelDetection.getPourVolume(UnitIndex::U1,
                                       LevelDetectionType::STATS),
        myTemp.getLastTempC(),
        myLevelDetection.hasStableWeight(UnitIndex::U1,
                                         LevelDetectionType::STATS));
    myDisplayLayout.showCurrent(
        UnitIndex::U2, myScale.isConnected(UnitIndex::U2),
        myLevelDetection.getBeerWeight(UnitIndex::U2, LevelDetectionType::RAW),
        myLevelDetection.getBeerVolume(UnitIndex::U2, LevelDetectionType::RAW),
        myLevelDetection.getNoGlasses(UnitIndex::U2, LevelDetectionType::STATS),
        myLevelDetection.getPourVolume(UnitIndex::U2,
                                       LevelDetectionType::STATS),
        myTemp.getLastTempC(),
        myLevelDetection.hasStableWeight(UnitIndex::U2,
                                         LevelDetectionType::STATS));
    PERF_END("loop-display-default");
    PERF_PUSH();

    /*Log.notice(
        F("LOOP: Reading data raw1=%F,raw2=%F,kalman1=%F,kalman2=%F,stab1=%F, "
          "stab2=%F,ave1=%F,ave2=%F,min1=%F,min2=%F,max1=%F,max2=%F,pour1=%F,"
          "pour2=%F" CR),
        myScale.getTotalRawWeight(UnitIndex::U1),
        myScale.getTotalRawWeight(UnitIndex::U2),
        myScale.getTotalWeight(UnitIndex::U1),
        myScale.getTotalWeight(UnitIndex::U2),
        myScale.getTotalStableWeight(UnitIndex::U1),
        myScale.getTotalStableWeight(UnitIndex::U2),
        myScale.getStatsDetection(UnitIndex::U1)->ave(),
        myScale.getStatsDetection(UnitIndex::U2)->ave(),
        myScale.getStatsDetection(UnitIndex::U1)->min(),
        myScale.getStatsDetection(UnitIndex::U2)->min(),
        myScale.getStatsDetection(UnitIndex::U1)->max(),
        myScale.getStatsDetection(UnitIndex::U2)->max(),
        myScale.getPourWeight(UnitIndex::U1),
        myScale.getPourWeight(UnitIndex::U2));*/
    Log.notice(
        F("LOOP: Reading data raw1=%F,raw2=%F,stable1=%F, "
          "stable2=%F,pour1=%F,"
          "pour2=%F" CR),
        myLevelDetection.getRawDetection(UnitIndex::U1)->getRawValue(),
        myLevelDetection.getRawDetection(UnitIndex::U2)->getRawValue(),
        myLevelDetection.getStatsDetection(UnitIndex::U1)->getStableValue(),
        myLevelDetection.getStatsDetection(UnitIndex::U2)->getStableValue(),
        myLevelDetection.getStatsDetection(UnitIndex::U1)->getPourValue(),
        myLevelDetection.getStatsDetection(UnitIndex::U2)->getPourValue());

    if (myConfig.hasTargetInfluxDb2()) {
      Log.notice(F("LOOP: Sending data to configured influxdb" CR));

      // This part is used to send data to an influxdb in order to get data on
      // scale stability/drift over time.
      char buf[250];

      float raw1 =
          myLevelDetection.getRawDetection(UnitIndex::U1)->getRawValue();
      float raw2 =
          myLevelDetection.getRawDetection(UnitIndex::U2)->getRawValue();
      float stb1 =
          myLevelDetection.getStatsDetection(UnitIndex::U1)->getStableValue();
      float stb2 =
          myLevelDetection.getStatsDetection(UnitIndex::U2)->getStableValue();

      String s;
      snprintf(&buf[0], sizeof(buf),
               "scale,host=%s,device=%s "
               "level-raw1=%f,"
               "level-raw2=%f",
               myConfig.getMDNS(), myConfig.getID(), isnan(raw1) ? 0 : raw1,
               isnan(raw2) ? 0 : raw2);
      s = &buf[0];

      float ave1 =
          myLevelDetection.getRawDetection(UnitIndex::U1)->getAverageValue();
      float ave2 =
          myLevelDetection.getRawDetection(UnitIndex::U2)->getAverageValue();

      snprintf(&buf[0], sizeof(buf), ",level-average1=%f,level-average2=%f",
               isnan(ave1) ? 0 : ave1, isnan(ave2) ? 0 : ave2);
      s += &buf[0];

      float kal1 =
          myLevelDetection.getRawDetection(UnitIndex::U1)->getKalmanValue();
      float kal2 =
          myLevelDetection.getRawDetection(UnitIndex::U2)->getKalmanValue();

      snprintf(&buf[0], sizeof(buf), ",level-kalman1=%f,level-kalman2=%f",
               isnan(kal1) ? 0 : kal1, isnan(kal2) ? 0 : kal2);
      s += &buf[0];

      float stats1 =
          myLevelDetection.getStatsDetection(UnitIndex::U1)->getStableValue();
      float stats2 =
          myLevelDetection.getStatsDetection(UnitIndex::U2)->getStableValue();

      snprintf(&buf[0], sizeof(buf), ",level-stats1=%f,level-stats2=%f",

               isnan(stats1) ? 0 : stats1, isnan(stats2) ? 0 : stats2);
      s += &buf[0];

      if (!isnan(myTemp.getLastTempC())) {
        snprintf(&buf[0], sizeof(buf), ",tempC=%f,tempF=%f",
                 myTemp.getLastTempC(), myTemp.getLastTempF());
        s = s + &buf[0];
      }

      if (!isnan(myTemp.getLastHumidity())) {
        snprintf(&buf[0], sizeof(buf), ",humidity=%f",
                 myTemp.getLastHumidity());
        s = s + &buf[0];
      }

      if (!isnan(stb1)) {
        snprintf(&buf[0], sizeof(buf), ",stable1=%f", stb1);
        s = s + &buf[0];
      }

      if (!isnan(stb2)) {
        snprintf(&buf[0], sizeof(buf), ",stable2=%f", stb2);
        s = s + &buf[0];
      }

#if LOG_LEVEL == 6
      Log.verbose(F("LOOP: %s" CR), s.c_str());
#endif
      myPush.sendInfluxDb2(
          s, myConfig.getTargetInfluxDB2(), myConfig.getOrgInfluxDB2(),
          myConfig.getBucketInfluxDB2(), myConfig.getTokenInfluxDB2());
    }
  }
}

void scanI2C(int sda, int scl) {
  byte error, address;
  int n = 0;

  Log.notice(F("Main: Scanning I2C bus on pins %d:%d for devices: "), sda, scl);

  for (address = 1; address < 127; address++) {
    // The i2c_scanner uses the return value of
    // the Write.endTransmisstion to see if
    // a device did acknowledge to the address.

    Wire.beginTransmission(address);
    error = Wire.endTransmission();

    if (error == 0) {
      EspSerial.print(address, HEX);
      EspSerial.print(",");
      n++;
    }
  }
  EspSerial.print("\n");
}

void logStartup() {
  struct tm timeinfo;
  time_t now = time(nullptr);
  char s[100];
  gmtime_r(&now, &timeinfo);

#if defined(ESP8266)
  snprintf(&s[0], sizeof(s),
           "%04d-%02d-%02d %02d:%02d:%02d;Starting up kegmon;%s\n",
           1900 + timeinfo.tm_year, 1 + timeinfo.tm_mon, timeinfo.tm_mday,
           timeinfo.tm_hour, timeinfo.tm_min, timeinfo.tm_sec,
           ESP.getResetInfo().c_str());
#else
  snprintf(&s[0], sizeof(s),
           "%04d-%02d-%02d %02d:%02d:%02d;Starting up kegmon;%d\n",
           1900 + timeinfo.tm_year, 1 + timeinfo.tm_mon, timeinfo.tm_mday,
           timeinfo.tm_hour, timeinfo.tm_min, timeinfo.tm_sec,
           rtc_get_reset_reason(0));
#endif

  File f = LittleFS.open(STARTUP_FILENAME, "a");

  if (f && f.size() > 2000) {
    f.close();
    LittleFS.remove(STARTUP_FILENAME);
    f = LittleFS.open(STARTUP_FILENAME, "a");
  }

  if (f) {
#if defined(ESP8266)
    f.write(&s[0], strlen(&s[0]));
#else
    f.write((unsigned char *)&s[0], strlen(&s[0]));
#endif
    f.close();
  }
}

void checkCoreDump() {
#if CONFIG_IDF_TARGET_ESP32S2
  esp_core_dump_summary_t *summary = static_cast<esp_core_dump_summary_t *>(
      malloc(sizeof(esp_core_dump_summary_t)));

  if (summary) {
    esp_log_level_set("esp_core_dump_elf", ESP_LOG_VERBOSE);

    if (esp_core_dump_get_summary(summary) == ESP_OK) {
      Log.notice(F("Exception cause %d." CR), summary->ex_info.exc_cause);
      Log.notice(F("PC 0x%x." CR), summary->exc_pc);

      for (int i = 0; i < summary->exc_bt_info.depth; i++) {
        Log.notice(F("PC(%d) 0x%x." CR), i, summary->exc_bt_info.bt[i]);
      }
    }
  }
#endif
}

// EOF

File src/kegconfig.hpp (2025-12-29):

/*
MIT License

Copyright (c) 2021-2024 Magnus

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
THE SOFTWARE IS PROVIDED "AS IS", WITHOUT WARRANTY OF ANY KIND, EXPRESS OR
IMPLIED, INCLUDING BUT NOT LIMITED TO THE WARRANTIES OF MERCHANTABILITY,
FITNESS FOR A PARTICULAR PURPOSE AND NONINFRINGEMENT. IN NO EVENT SHALL THE
AUTHORS OR COPYRIGHT HOLDERS BE LIABLE FOR ANY CLAIM, DAMAGES OR OTHER
LIABILITY, WHETHER IN AN ACTION OF CONTRACT, TORT OR OTHERWISE, ARISING FROM,
OUT OF OR IN CONNECTION WITH THE SOFTWARE OR THE USE OR OTHER DEALINGS IN THE
SOFTWARE.
 */
#ifndef SRC_KEGCONFIG_HPP_
#define SRC_KEGCONFIG_HPP_

#include <baseconfig.hpp>
#include <main.hpp>

constexpr auto PARAM_BREWLOGGER_URL = "brewlogger_url";
constexpr auto PARAM_BREWFATHER_USERKEY = "brewfather_userkey";
constexpr auto PARAM_BREWFATHER_APIKEY = "brewfather_apikey";
constexpr auto PARAM_BREWSPY_TOKEN1 = "brewspy_token1";
constexpr auto PARAM_BREWSPY_TOKEN2 = "brewspy_token2";
constexpr auto PARAM_BREWPI_URL = "brewpi_url";
constexpr auto PARAM_CHAMBERCTRL_URL = "chamberctrl_url";
constexpr auto PARAM_BARHELPER_APIKEY = "barhelper_apikey";
constexpr auto PARAM_BARHELPER_MONITOR1 = "barhelper_monitor1";
constexpr auto PARAM_BARHELPER_MONITOR2 = "barhelper_monitor2";
constexpr auto PARAM_DISPLAY_LAYOUT = "display_layout";
constexpr auto PARAM_TEMP_SENSOR = "temp_sensor";
constexpr auto PARAM_DISPLAY_DRIVER = "display_driver";
constexpr auto PARAM_SCALE_SENSOR = "scale_sensor";
constexpr auto PARAM_WEIGHT_UNIT = "weight_unit";
constexpr auto PARAM_VOLUME_UNIT = "volume_unit";
constexpr auto PARAM_KEG_WEIGHT1 = "keg_weight1";
constexpr auto PARAM_KEG_WEIGHT2 = "keg_weight2";
constexpr auto PARAM_KEG_VOLUME1 = "keg_volume1";
constexpr auto PARAM_KEG_VOLUME2 = "keg_volume2";
constexpr auto PARAM_GLASS_VOLUME1 = "glass_volume1";
constexpr auto PARAM_GLASS_VOLUME2 = "glass_volume2";
constexpr auto PARAM_BEER_NAME1 = "beer_name1";
constexpr auto PARAM_BEER_NAME2 = "beer_name2";
constexpr auto PARAM_BEER_ID1 = "beer_id1";
constexpr auto PARAM_BEER_ID2 = "beer_id2";
constexpr auto PARAM_BEER_ABV1 = "beer_abv1";
constexpr auto PARAM_BEER_ABV2 = "beer_abv2";
constexpr auto PARAM_BEER_IBU1 = "beer_ibu1";
constexpr auto PARAM_BEER_IBU2 = "beer_ibu2";
constexpr auto PARAM_BEER_EBC1 = "beer_ebc1";
constexpr auto PARAM_BEER_EBC2 = "beer_ebc2";
constexpr auto PARAM_BEER_FG1 = "beer_fg1";
constexpr auto PARAM_BEER_FG2 = "beer_fg2";
constexpr auto PARAM_SCALE_FACTOR1 = "scale_factor1";
constexpr auto PARAM_SCALE_FACTOR2 = "scale_factor2";
constexpr auto PARAM_SCALE_OFFSET1 = "scale_offset1";
constexpr auto PARAM_SCALE_OFFSET2 = "scale_offset2";
constexpr auto PARAM_SCALE_TEMP_FORMULA1 = "scale_temp_formula1";
constexpr auto PARAM_SCALE_TEMP_FORMULA2 = "scale_temp_formula2";
constexpr auto PARAM_SCALE_DEVIATION_INCREASE = "scale_deviation_increase";
constexpr auto PARAM_SCALE_DEVIATION_DECREASE = "scale_deviation_decrease";
constexpr auto PARAM_SCALE_DEVIATION_KALMAN = "scale_deviation_kalman";
constexpr auto PARAM_SCALE_READ_COUNT = "scale_read_count";
constexpr auto PARAM_SCALE_READ_COUNT_CALIBRATION =
    "scale_read_count_calibration";
constexpr auto PARAM_SCALE_STABLE_COUNT = "scale_stable_count";
constexpr auto PARAM_LEVEL_DETECTION = "level_detection";
constexpr auto PARAM_KALMAN_NOISE = "kalman_noise";
constexpr auto PARAM_KALMAN_MEASUREMENT = "kalman_measurement";
constexpr auto PARAM_KALMAN_ESTIMATION = "kalman_estimation";
constexpr auto PARAM_KALMAN_ACTIVE = "kalman_active";

struct BeerInfo {
  String _name = "";
  float _abv = 0.0;
  int _ebc = 0;
  int _ibu = 0;
  float _fg = 1;
  String _id = "";
};

struct HardwareInfo {
#if defined(ESP8266)
  int _displayData = D2;
  int _displayClock = D1;
  int _scale1Data = D3;
  int _scale1Clock = D4;
  int _scale2Data = D5;
  int _scale2Clock = D8;
  int _tempData = D7;
  int _tempPower = D6;
#elif defined(ESP32S2)
  int _displayData = SDA;
  int _displayClock = SCL;
  int _scale1Data = A17;
  int _scale1Clock = A15;
  int _scale2Data = A6;
  int _scale2Clock = A11;
  int _tempData = A10;
  int _tempPower = A8;
#elif defined(ESP32S3)
  int _displayData = SDA;
  int _displayClock = SCL;
  int _scale1Data = A17;
  int _scale1Clock = A15;
  int _scale2Data = A11;
  int _scale2Clock = A9;
  int _tempData = A10;
  int _tempPower = A12;
#else
#error "Not a supported target"
#endif
};

constexpr auto PARAM_PIN_DISPLAY_DATA = "pin_display_data";
constexpr auto PARAM_PIN_DISPLAY_CLOCK = "pin_display_clock";
constexpr auto PARAM_PIN_SCALE1_DATA = "pin_scale1_data";
constexpr auto PARAM_PIN_SCALE1_CLOCK = "pin_scale1_clock";
constexpr auto PARAM_PIN_SCALE2_DATA = "pin_scale2_data";
constexpr auto PARAM_PIN_SCALE2_CLOCK = "pin_scale2_clock";
constexpr auto PARAM_PIN_TEMP_DATA = "pin_temp_data";
constexpr auto PARAM_PIN_TEMP_POWER = "pin_temp_power";

constexpr auto WEIGHT_KG = "kg";
constexpr auto WEIGHT_LBS = "lbs";

constexpr auto VOLUME_CL = "cl";
constexpr auto VOLUME_US = "us-oz";
constexpr auto VOLUME_UK = "uk-oz";
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

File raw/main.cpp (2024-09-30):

/*
MIT License

Copyright (c) 2022 Magnus

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
THE SOFTWARE IS PROVIDED "AS IS", WITHOUT WARRANTY OF ANY KIND, EXPRESS OR
IMPLIED, INCLUDING BUT NOT LIMITED TO THE WARRANTIES OF MERCHANTABILITY,
FITNESS FOR A PARTICULAR PURPOSE AND NONINFRINGEMENT. IN NO EVENT SHALL THE
AUTHORS OR COPYRIGHT HOLDERS BE LIABLE FOR ANY CLAIM, DAMAGES OR OTHER
LIABILITY, WHETHER IN AN ACTION OF CONTRACT, TORT OR OTHERWISE, ARISING FROM,
OUT OF OR IN CONNECTION WITH THE SOFTWARE OR THE USE OR OTHER DEALINGS IN THE
SOFTWARE.
 */
#include <display.hpp>
#include <kegconfig.hpp>
#include <kegpush.hpp>
#include <main.hpp>
#include <ota.hpp>
#include <scale.hpp>
#include <temp_mgr.hpp>
#include <utils.hpp>
#include <wificonnection.hpp>
#include "simulated.hpp"

SerialDebug mySerial(115200L);
KegConfig myConfig(CFG_MDNSNAME, CFG_FILENAME);
WifiConnection myWifi(&myConfig, CFG_APPNAME, "password", CFG_MDNSNAME);
OtaUpdate myOta(&myConfig, CFG_APPVER);
KegPushHandler myPush(&myConfig);
Display myDisplay;
TempSensorManager myTemp;
LevelDetection myLevelDetection;

void setup() {
  Log.notice(F("Level detection simulator" CR));
  myDisplay.setup();
  myConfig.checkFileSystem();

  myConfig.loadFile();
  myWifi.init();

  // Disable BrewSpy and HA integration for the tests.
  myConfig.setTargetMqtt("");
  myConfig.setPassMqtt("");
  myConfig.setUserMqtt("");
  myConfig.setBrewspyToken(UnitIndex::U1, "");
  myConfig.setBrewspyToken(UnitIndex::U1, "");

  String formula = "";
  // String formula = "weight*(1.0-0.025*(tempC-3.0))";
  // String formula = "weight*(1+(0.004*(tempC-5)))";
  // String formula = "weight-(1+0.004*(tempC-5))";
  myConfig.setScaleTempCompensationFormula(UnitIndex::U1, formula);
  myConfig.setScaleTempCompensationFormula(UnitIndex::U2, formula);

  if (!myWifi.hasConfig() || myWifi.isDoubleResetDetected()) {
    Log.notice(
        F("Main: Missing wifi config or double reset detected, entering wifi "
          "setup." CR));

    myDisplay.clear(UnitIndex::U1);
    myDisplay.setFont(UnitIndex::U1, FontSize::FONT_16);
    myDisplay.printLineCentered(UnitIndex::U1, 0, "Entering");
    myDisplay.printLineCentered(UnitIndex::U1, 1, "WIFI Portal");
    myDisplay.printLineCentered(UnitIndex::U1, 2, "192.168.4.1");
    myDisplay.show(UnitIndex::U1);
    myWifi.startAP();
  }

  myWifi.connect();
  Log.notice(F("Main: Setup completed." CR));
  delay(3000);
  myDisplay.clear(UnitIndex::U1);
  myDisplay.setFont(UnitIndex::U1, FontSize::FONT_10);
  myDisplay.printLineCentered(UnitIndex::U1, 0, "Running");
  myDisplay.show(UnitIndex::U1);

  // Change setting for the simulation
  Log.notice(F("SETUP: Max deviation increase %F" CR), myConfig.getScaleDeviationIncreaseValue());
  Log.notice(F("SETUP: Max deviation decrease %F" CR), myConfig.getScaleDeviationDecreaseValue());
}

int simulatedIndex = 0;
// int simulatedDelay = 1000;
// int simulatedDelay = 500;
// int simulatedDelay = 200;
int simulatedDelay = 100;
// int simulatedDelay = 50;

void loop() {
  if (!myWifi.isConnected()) myWifi.connect();

  myWifi.loop();

  if (simulatedData[simulatedIndex].scale1 > 0.0) {
    float t = simulatedData[simulatedIndex].temp; 
    // float v = simulatedData[simulatedIndex].scale1; 
    float v = simulatedData[simulatedIndex].scale2; 

    myLevelDetection.update(UnitIndex::U1, v, t);

    Log.verbose(
        F("LOOP: Input: %F, output: raw1=%F,stable1=%F"
          ",pour1=%F [%d]" CR), v,
        myLevelDetection.getRawDetection(UnitIndex::U1)->getRawValue(),
        myLevelDetection.getStatsDetection(UnitIndex::U1)->getStableValue(),
        myLevelDetection.getStatsDetection(UnitIndex::U1)->getPourValue(), simulatedIndex);
    Serial.print(".");

#if defined(ENABLE_INFLUX_DEBUG)
    // This part is used to send data to an influxdb in order to get data on
    // scale stability/drift over time.
    char buf[250];

    float raw1 = myLevelDetection.getRawDetection(UnitIndex::U1)->getRawValue();

    String s;
    snprintf(&buf[0], sizeof(buf),
             "simulate,host=%s,device=%s "
             "level-raw1=%f,temp=%f",
             myConfig.getMDNS(), myConfig.getID(), isnan(raw1) ? 0 : raw1, t);
    s = &buf[0];

    float ave1 =
        myLevelDetection.getRawDetection(UnitIndex::U1)->getAverageValue();

    if (!isnan(ave1)) {
      snprintf(&buf[0], sizeof(buf), ",level-average1=%f",
              isnan(ave1) ? 0 : ave1);
      s += &buf[0];
    }

    float kal1 = myLevelDetection.getRawDetection(UnitIndex::U1)->getKalmanValue();

    if (kal1 > 0.1  && !isnan(kal1)) {
      snprintf(&buf[0], sizeof(buf), ",level-kalman1=%f",
              isnan(kal1) ? 0 : kal1);
      s += &buf[0];
    }

    float stats1 =
        myLevelDetection.getStatsDetection(UnitIndex::U1)->getStableValue();

    if( stats1 > 0  && !isnan(stats1)) { // Skip the 0 values to make focus the scale in influx.
      snprintf(&buf[0], sizeof(buf), ",level-stats1=%f",
              isnan(stats1) ? 0 : stats1);
      s += &buf[0];
    }

    float temp1 =
        myLevelDetection.getRawDetection(UnitIndex::U1)->getTempCorrValue();

    if( temp1 > 0 && !isnan(temp1)) { // Skip the 0 values to make focus the scale in influx.
      snprintf(&buf[0], sizeof(buf), ",level-temp1=%f",
              isnan(temp1) ? 0 : temp1);
      s += &buf[0];
    }

    float slope1 =
        myLevelDetection.getRawDetection(UnitIndex::U1)->getSlopeValue();

    if(!isnan(slope1)) { 
      snprintf(&buf[0], sizeof(buf), ",level-slope1=%f",
              isnan(slope1) ? 0 : slope1);
      s += &buf[0];
    }

    float tempCorr1 =
        myLevelDetection.getRawDetection(UnitIndex::U1)->getTempCorrValue();

    if(!isnan(tempCorr1)) { 
      snprintf(&buf[0], sizeof(buf), ",level-temp=%f",
              isnan(tempCorr1) ? 0 : tempCorr1);
      s += &buf[0];
    }

    Log.verbose(F("%s" CR), s.c_str());

    // Change loglevel to avoid filling console with trace information
    Log.setLevel(LOG_LEVEL_WARNING);
    myPush.sendInfluxDb2(s, PUSH_INFLUX_TARGET, PUSH_INFLUX_ORG,
                         PUSH_INFLUX_BUCKET, PUSH_INFLUX_TOKEN);
    Log.setLevel(LOG_LEVEL);
#endif  // ENABLE_INFLUX_DEBUG

    simulatedIndex++;
    delay(simulatedDelay);
  } else {
    myDisplay.clear(UnitIndex::U1);
    myDisplay.setFont(UnitIndex::U1, FontSize::FONT_10);
    myDisplay.printLineCentered(UnitIndex::U1, 0, "Done");
    myDisplay.show(UnitIndex::U1);
    delay(1000);
  }
}

// EOF

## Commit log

2022-05-02 Prototype working
2022-05-03 Added calibration workflow
2022-06-09 Switch theme
2022-06-11 Disable temp sensor if not found
2022-09-07 Fixed busy indicator when calibrating
2022-09-10 Filter out values that are too high
2022-09-16 Added kalman filter and brewspy integration
2022-12-13 Added option to set stability time
    [kegconfig.cpp, kegconfig.hpp]
2023-01-01 Exposed settings for kalman filter
2023-01-06 Updated level detection with kalman filter
2023-01-07 Bug fixes in b5 and added temp graph
    [kegconfig.cpp, kegconfig.hpp, kegwebhandler.cpp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]
2023-02-02 Minor changes to fix issues
    [kegconfig.cpp, kegconfig.hpp, kegwebhandler.cpp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]
2023-02-18 Fixes in calibration flow
    [kegwebhandler.cpp, main.cpp]
2023-03-03 Added esp32 support
2023-03-03 Added part for esp32
    [part32.csv]
2023-03-04 Temp sensor init check
2023-03-05 Added support for ds temp sensor
2023-03-05 Fix build script for esp32
2023-03-07 Refactored i2c scanner
2023-03-16 Fixed cleanup with sockets
    [main.cpp]
2023-04-11 Added schema and pcb for HX711
    [kegmon_hx711.brd, kegmon_hx711.sch]
2023-04-24 Added dashboard, pcb and case
    [case_base.3mf, case_lid.3mf, scale_base.3mf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]
2023-05-05 Added driver for LCD 20x4
2023-06-10 Update arduino versions
2023-06-12 Adding reset reason to s2 + fix bug in influx push
    [main.cpp]
2023-06-12 Correct use of espserial wss init
    [main.cpp]
2023-06-12 Adjusted hass device registration
2023-06-13 Update arduino version
2023-06-14 Dont send temp to hass if no sensor is attached
2023-06-19 Added partition file with coredump partition
    [part32_coredump.csv]
2023-07-30 move code around and split sensors
2023-08-05 check sensor more often
2023-08-07 Adjused code to work with esp32
2023-08-28 Change default temp sensor
2023-08-31 Fixed build for esp32s2
    [scale_nau7802.cpp]
2023-08-31 Fixed reset logic for temp sensors
    [main.cpp, scale_nau7802.cpp]
2023-09-03 Upd esp32 deps
2023-09-13 Update version + fix json issues + upd gha
    [kegconfig.cpp]
2023-10-05 Revert arduino version to 5.4
    [main.cpp]
2023-10-12 Fix issue with dht22 sensor not being detected as missing
2023-10-21 Adding brewpi as temp sensor
2023-12-18 Added support for s3 board
2024-07-28 Fixed old config conversion
    [kegconfig.cpp]
2024-08-29 Change wire speed to 400mhz
2024-09-10 Switch to onewireNG
2024-09-11 Switched to non ssl for esp8266 for barhelper
2024-10-24 Fixed url for brewlogger
    [brewlogger.cpp]
2024-12-07 Add support for chamber controller
2025-12-29 Update dependcies and minor fixes for 1.2
    [kegconfig.cpp, kegconfig.hpp, kegwebhandler.cpp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]
2026-10-26 feat: integrate BrewGraph functionality
    - Updated package dependencies for Vitest and ESLint plugin.
    - Enhanced config store to include BrewGraph URL and tokens.
    - Added routing for BrewGraph integration view.
    - Implemented status store to manage BrewGraph state.
    - Updated HomeView to display BrewGraph push status.
    - Created IntBrewgraphView for BrewGraph configuration.
    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
2026-11-01 feat: update Arduino Temperature Control Library dependency to a specific commit for stability
2026-11-01 feat: add temperature parameter to BrewGraph pour and keg information updates

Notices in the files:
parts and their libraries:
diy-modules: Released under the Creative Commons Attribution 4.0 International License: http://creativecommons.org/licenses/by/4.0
